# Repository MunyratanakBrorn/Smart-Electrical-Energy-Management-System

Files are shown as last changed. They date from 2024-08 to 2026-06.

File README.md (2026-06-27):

<div align="center">

# ⚡ Smart Electrical Energy Management System
### SEEMS

<p>
  <em>A distributed IoT platform for real-time monitoring, control, and optimization of electrical energy.</em>
</p>

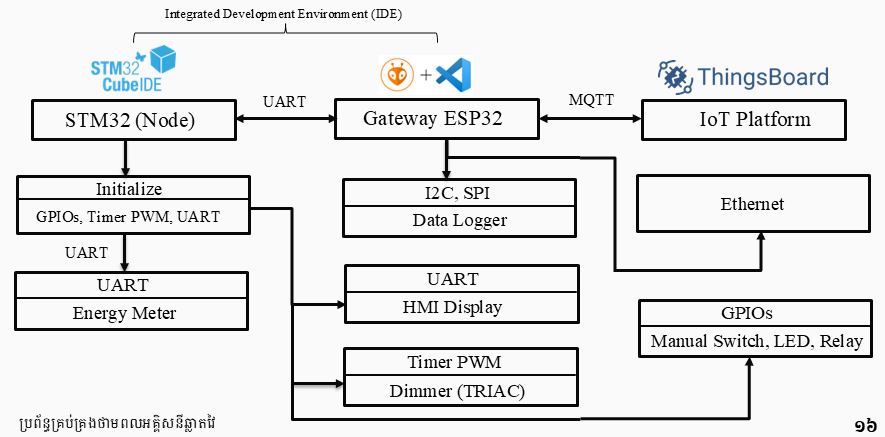
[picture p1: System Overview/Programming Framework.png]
SEEMS System Diagram


<br><br>








</div>

> 💡 **This is a public template.** Use it to bootstrap your own energy-monitoring node — click **"Use this template"** above.

---

## 📌 Table of Contents

- [About the Project](#-about-the-project)
- [Key Features](#-key-features)
- [System Architecture](#-system-architecture)
- [End-to-End Workflow](#-end-to-end-workflow)
- [Project Visuals](#-project-visuals)
- [Tech Stack](#-tech-stack)
- [Hardware Components](#-hardware-components)
- [Communication Protocols](#-communication-protocols)
- [Getting Started](#-getting-started)
- [Repository Structure](#-repository-structure)
- [Authors](#-authors)
- [License](#-license)

---

## 🌐 About the Project

The **Smart Electrical Energy Management System (SEEMS)** is a scalable, IoT-based solution that monitors, controls, and optimizes electrical energy consumption in real time. Built on a **distributed architecture** — STM32 controller nodes paired with an ESP32 gateway and a **ThingsBoard cloud platform** — the system is suitable for **residential, commercial, and industrial** deployments.

Developed as a **Final Year Thesis** for the **Bachelor of Technology in Electronics Engineering** at **Preah Kossomak Polytechnic Institute** (Class of 2024).

---

## ✨ Key Features

| | Feature | Description |
|---|---|---|
| 📊 | **Real-Time Monitoring** | Live voltage, current, power, and energy readings |
| 🎛️ | **Local & Remote Control** | Switch loads via HMI touchscreen or remotely over the cloud |
| ☁️ | **Cloud Dashboard (ThingsBoard)** | Remote telemetry, visualization, and control via MQTT |
| 🔆 | **Dimmer Control (TRIAC)** | Phase-angle dimming for adjustable loads |
| 🧩 | **Distributed & Modular** | Add controller nodes without re-architecting the system |
| 🗄️ | **Onboard Data Logging** | Local logging over I2C/SPI for resilience |
| 🖥️ | **Intuitive HMI** | Touch dashboard built with SquareLine Studio |
| 🔌 | **Reliable Actuation** | Relay-based load switching with safe-state handling |

---

## 🧠 System Architecture

SEEMS follows a **gateway–node** topology. A central **ESP32 gateway** coordinates one or more **STM32F405 controller nodes** for local sensing and actuation, then publishes telemetry to the **ThingsBoard IoT platform** over **MQTT** for remote monitoring and control.

<div align="center">
  <a href="System Overview/Hardware System diagram.jpg" target="_blank">
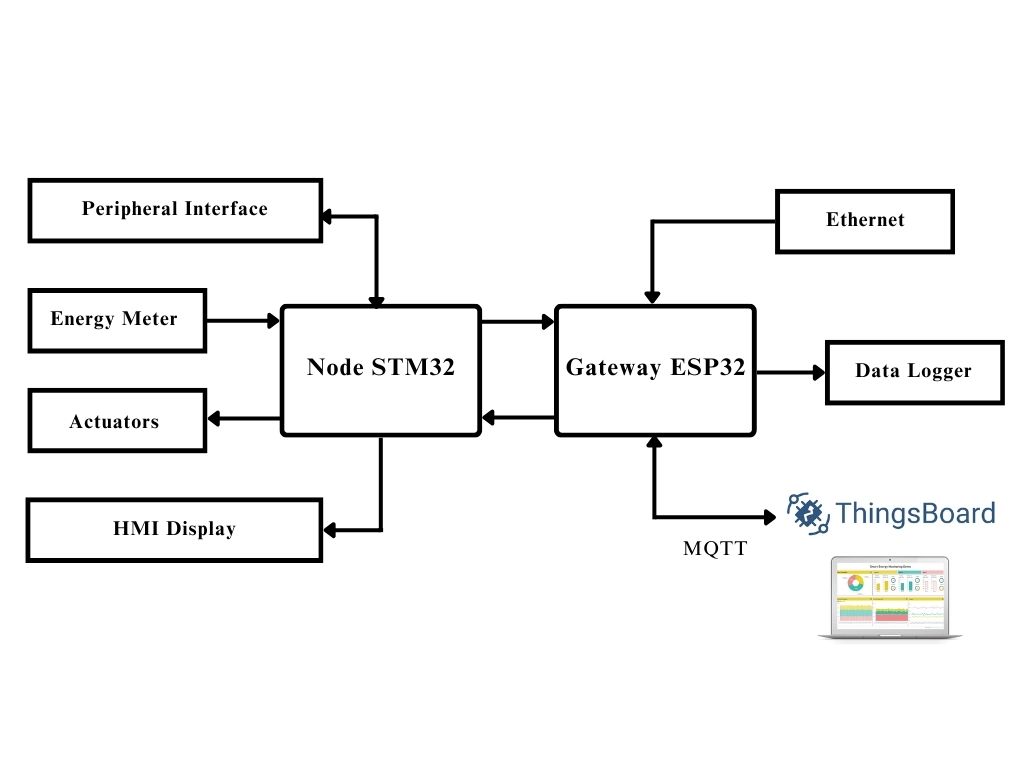
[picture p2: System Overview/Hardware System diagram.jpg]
SEEMS Architecture Diagram
    
  </a>
  <br>
  <em>Click to view full resolution.</em>
</div>

| Layer | Component | Responsibility |
|---|---|---|
| **Edge** | STM32F405 Node | Measure V/I, compute power & energy, drive relays & TRIAC dimmer |
| **Gateway** | ESP32-WROOM-32U | Aggregate data, manage Wi-Fi/Ethernet, publish MQTT to cloud |
| **Cloud** | ThingsBoard | Remote dashboards, telemetry storage, control commands |
| **Interface** | HMI Display | Real-time feedback and local user control |
| **Logging** | Data Logger (I2C/SPI) | Persist measurements locally |

---

## 🔄 End-to-End Workflow

```mermaid
flowchart LR
    A[AC Load] -->|sensing| B[Energy Meter<br/>BL0910]
    B -->|UART| C[STM32F405<br/>Controller Node]
    C -->|power / energy| D[HMI Display]
    C -->|I2C / SPI| H[Data Logger]
    C -->|UART| E[ESP32 Gateway]
    E -->|MQTT over Wi-Fi / Ethernet| F[(ThingsBoard<br/>IoT Platform)]
    F -->|remote command| E
    D -->|local command| C
    E -->|control| C
    C -->|Relay switch| G[Load ON/OFF]
    C -->|Timer PWM| I[TRIAC Dimmer]
```

**Sequence**

1. **Measurement** — The BL0910 IC senses AC voltage and current.
2. **Processing** — The STM32F405 computes power and energy metrics.
3. **Display & Logging** — Results are pushed to the HMI and logged locally via I2C/SPI.
4. **Communication** — Data travels to the ESP32 over UART.
5. **Gateway & Cloud** — The ESP32 publishes telemetry to ThingsBoard via MQTT (over Wi-Fi/Ethernet).
6. **Actuation** — Relays switch loads and the TRIAC dimmer adjusts brightness, based on local or remote input.

---

## 🎬 Live Demo

<div align="center">
  SEEMS animated demo: relay ON/OFF switching and live energy metering
  <br>
  <em>Animated overview — relay <strong>ON/OFF</strong> load switching and live <strong>energy metering</strong> (voltage, current, power, energy).</em>
</div>

> ℹ️ The animation is an inline SVG (`seems-animation.svg`) — it plays automatically on GitHub with no external dependencies.

---

## 🖼️ Project Visuals

<table>
  <tr>
    <th align="center">Main Dashboard</th>
    <th align="center">Real-Time Graph</th>
  </tr>
  <tr>
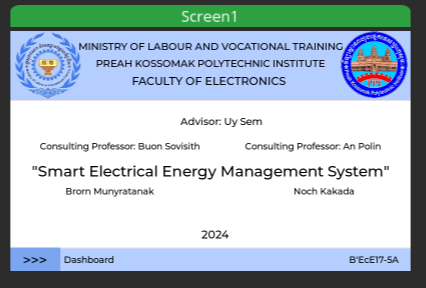
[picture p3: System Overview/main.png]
    <td></td>
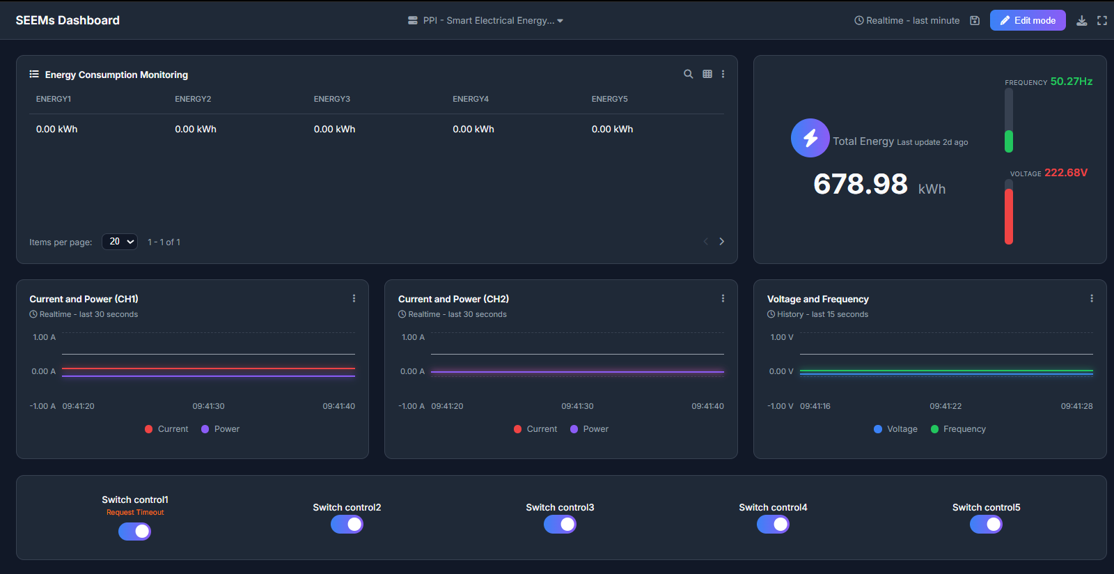
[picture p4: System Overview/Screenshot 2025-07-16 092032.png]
    <td></td>
  </tr>
</table>

---

## 🧰 Tech Stack

**Languages:** C · C++

| Target | Toolchain / Framework |
|---|---|
| ESP32 Gateway | PlatformIO + Arduino Framework |
| STM32 Node | STM32CubeIDE (HAL) |
| HMI | SquareLine Studio |
| Cloud Platform | ThingsBoard (MQTT) |

---

## 🔩 Hardware Components

| Component | Description | Role |
|---|---|---|
| **ESP32-WROOM-32U** | Wi-Fi-enabled MCU | Data aggregation, MQTT cloud gateway |
| **STM32F405RG** | High-performance Cortex-M4 MCU | Sensing, processing, load & dimmer control |
| **BL0910** | Energy metering IC | AC voltage/current sensing |
| **TRIAC Dimmer** | Phase-angle control circuit | Adjustable lighting/load dimming |
| **HMI Display** | SquareLine Studio UI | User interface |
| **12V Songle Relays** | Electromechanical switch | Load on/off control |
| **Data Logger** | I2C/SPI storage | Local measurement logging |

---

## 🔗 Communication Protocols

| Protocol | Link | Purpose |
|---|---|---|
| **UART** | STM32 ↔ ESP32 · STM32 ↔ Energy Meter | Inter-MCU & sensor data exchange |
| **MQTT** | ESP32 ↔ ThingsBoard | Cloud telemetry & remote control |
| **Wi-Fi / Ethernet** | ESP32 ↔ Network | Internet connectivity |
| **I2C / SPI** | STM32 ↔ Data Logger | Local data logging |
| **Timer PWM** | STM32 ↔ TRIAC | Phase-angle dimming control |

---

## 🚀 Getting Started

### Prerequisites

- [STM32CubeIDE](https://www.st.com/en/development-tools/stm32cubeide.html)
- [PlatformIO for VS Code](https://platformio.org/)
- A [ThingsBoard](https://thingsboard.io/) account or self-hosted instance
- Hardware components listed above

### Hardware Setup

1. Assemble components per the schematics in `Hardware/`.
2. Verify connections between the STM32, ESP32, BL0910 sensors, data logger, TRIAC dimmer, and HMI.

### Firmware Upload

| Target | Steps |
|---|---|
| **STM32 Node** | Open `Firmware/STM32_F405_Controller Node/` in STM32CubeIDE → build → flash |
| **ESP32 Gateway** | Open `Firmware/ESP32_Gateway_SEEMs/` in PlatformIO → set Wi-Fi + ThingsBoard MQTT credentials → upload |
| **HMI** | Open `Firmware/HMI Screen display/` in SquareLine Studio → export → load `.tft` via SD card |

### Cloud Setup (ThingsBoard)

1. Create a new **Device** in ThingsBoard and copy its access token.
2. Set the token and broker host in the ESP32 firmware configuration.
3. Import or build a dashboard to visualize incoming telemetry.

### Run

1. Power on all devices.
2. The HMI loads the dashboard.
3. The ESP32 connects to the network and publishes telemetry to ThingsBoard.
4. The system is live for real-time local **and** remote monitoring and control.

---

## 📁 Repository Structure

```
📦 SEEMS
├── 📂 Firmware/
│   ├── 📂 ESP32_Gateway_SEEMs/
│   ├── 📂 STM32_F405_Controller Node/
│   └── 📂 HMI Screen display/
├── 📂 Hardware/
├── 📂 System Overview/
├── 📂 Thesis Report and presentation/
└── 📄 README.md
```

---

## 👥 Authors

| Name | Role |
|---|---|
| **Brorn Munyratanak** | Co-developer |
| **Noch Kakada** | Co-developer |

Final Year Thesis · **Electronics Engineering** · **Preah Kossomak Polytechnic Institute** (Class of 2024)

> Special thanks to our advisors and faculty for their guidance throughout the project.

---

## 📜 License

Licensed under the [MIT License](https://opensource.org/licenses/MIT).

<div align="center">
  <sub>Built with ⚡ for a smarter, more efficient energy future.</sub>
</div>

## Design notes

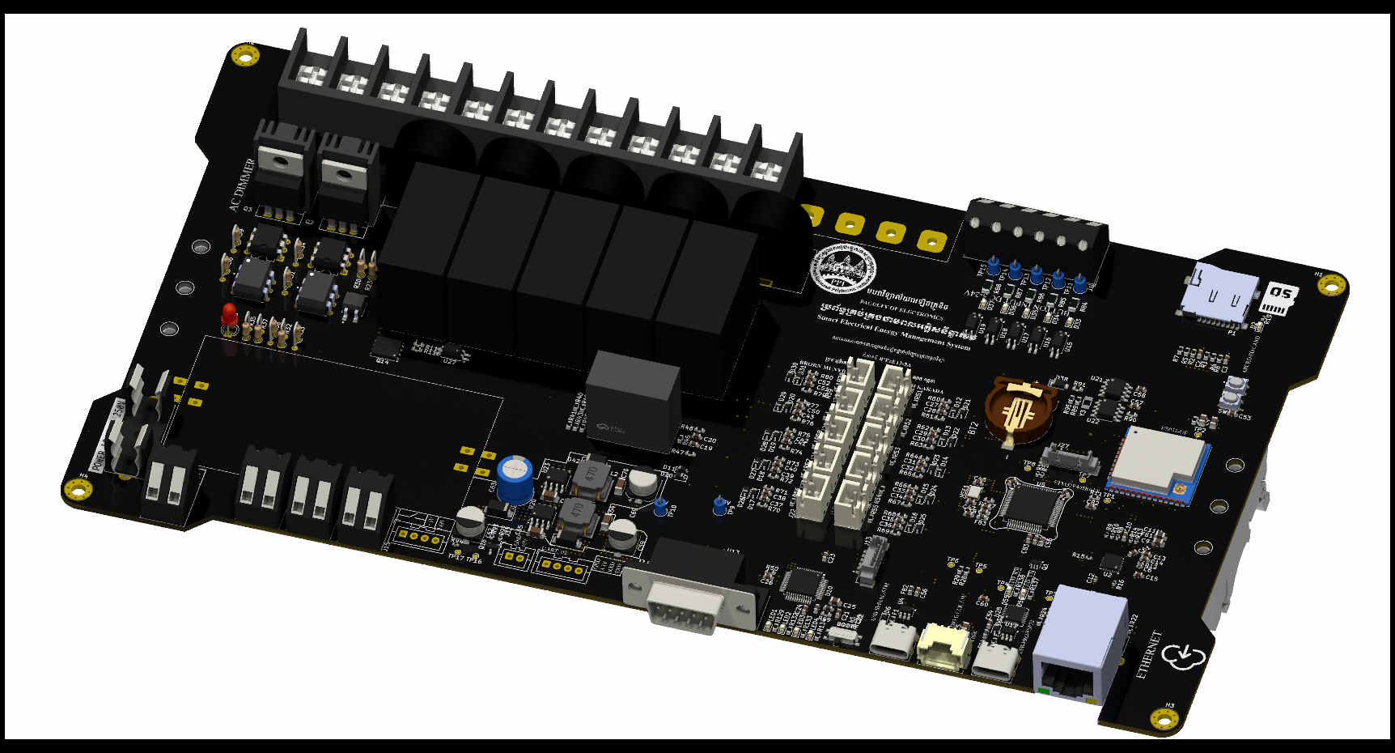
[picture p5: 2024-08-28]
Hardware/SmartEnergyMag_System PCB deisgn/SmartEnergyMag_System2.png

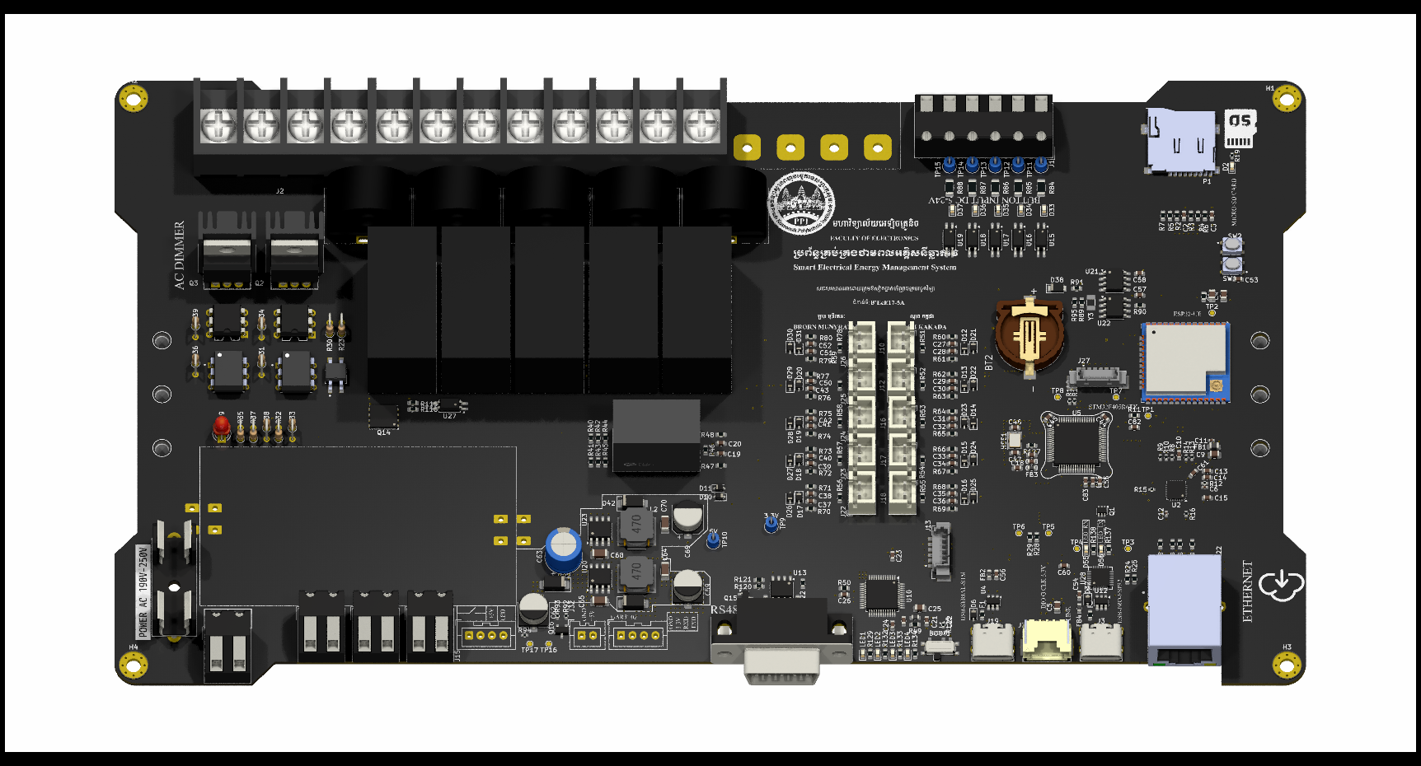
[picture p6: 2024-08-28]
Hardware/SmartEnergyMag_System PCB deisgn/SmartEnergyMag_System3.png

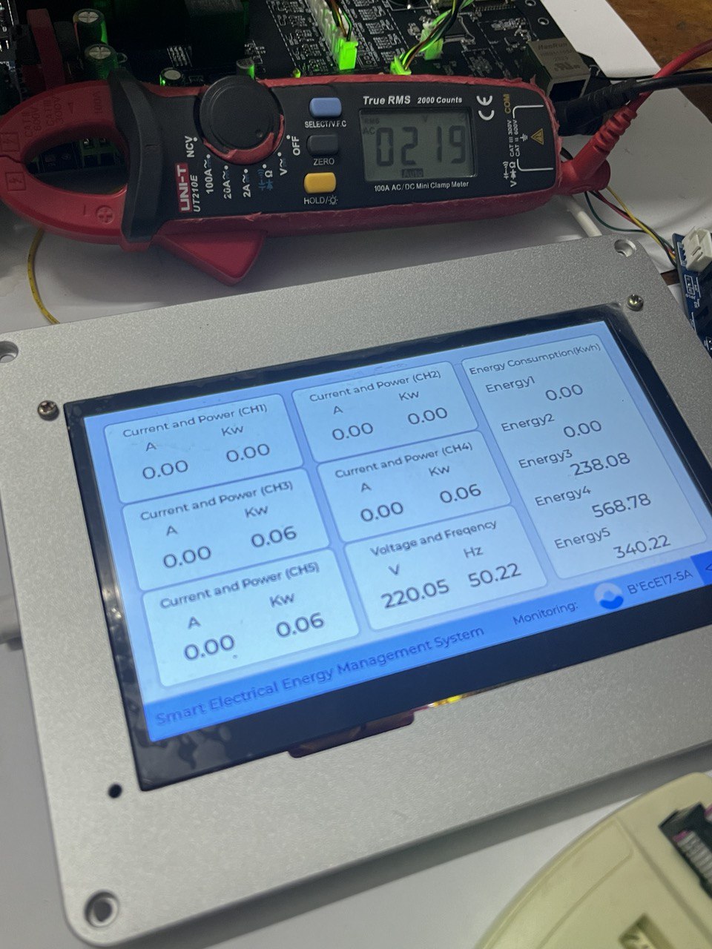
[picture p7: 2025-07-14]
System Overview/dasborad.jpg

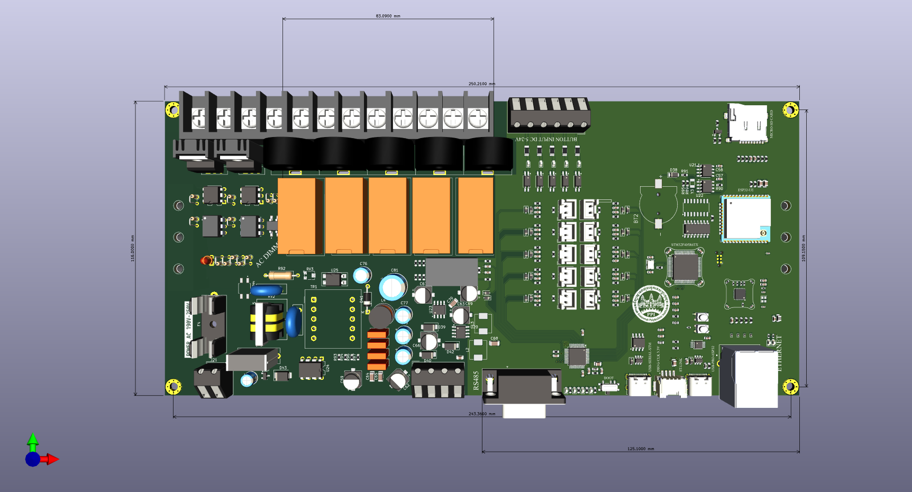
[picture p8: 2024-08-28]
Hardware/SmartEnergyMag_System PCB deisgn/SmartEnergyMag_System1.png

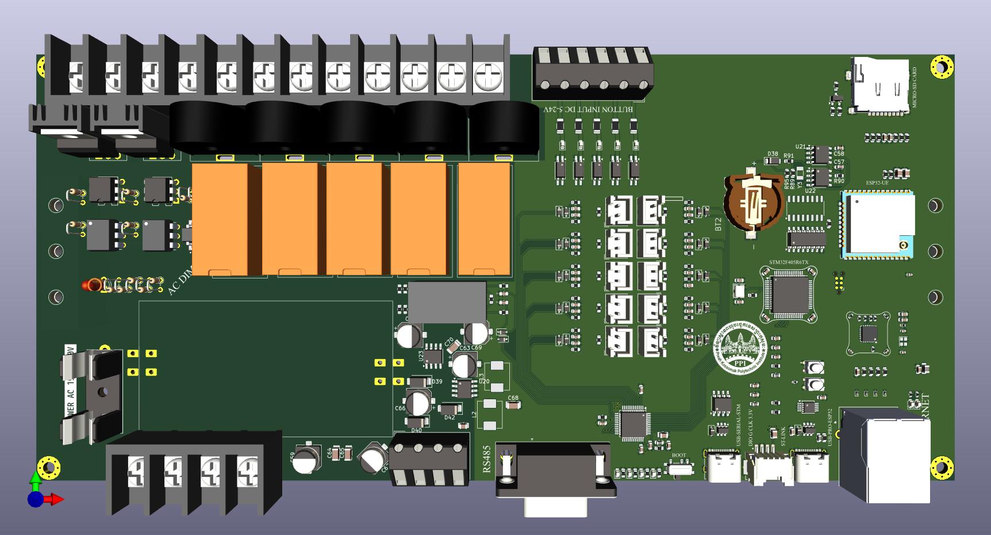
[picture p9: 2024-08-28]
Hardware/SmartEnergyMag_System PCB deisgn/SmartEnergyMag_System.jpg

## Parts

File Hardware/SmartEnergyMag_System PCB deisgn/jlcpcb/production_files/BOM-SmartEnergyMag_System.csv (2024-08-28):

Comment | Designator | Footprint | LCSC
XL1509-3.3 | U20 | SOIC-8_3.9x4.9mm_P1.27mm | C2681226
XL1509-5.0 | U23 | SOIC-8_3.9x4.9mm_P1.27mm | C2902368
510R | R84,R85,R86,R87,R88 | R_1206_3216Metric | C3017298
220uF/16V | C59,C62,C63,C69 | CP_Elec_6.3x4.5 | C59918
C7506797 | J19 | USB_C_Receptacle_G-Switch_GT-USB-7010ASV | C7506797
30R | R59 | R_0603_1608Metric
Conn_01x02_Pin | J26 | JST_XH_B2B-XH-A_1x02_P2.50mm_Vertical
10K | R3 | R_0603_1608Metric
100n | C60 | C_0603_1608Metric
330 | R133 | R_0603_1608Metric
Relay_SPST-NO | K1 | K88A
MOC3021M | U7 | DIP-6_W7.62mm
LED | D36 | LED_0603_1608Metric
Conn_01x02_Pin | J22 | JST_XH_B2B-XH-A_1x02_P2.50mm_Vertical
1N4148WS | D17 | D_SOD-323
49.9R | R20 | R_0603_1608Metric
1K | R31 | R_Axial_DIN0204_L3.6mm_D1.6mm_P2.54mm_Vertical
30R | R53 | R_0603_1608Metric
33nF | C26 | C_0603_1608Metric
Relay_SPST-NO | K5 | K88A
0R | R15 | R_0402_1005Metric
30R | R52 | R_0603_1608Metric
30R | R78 | R_0603_1608Metric
1N4148WS | D11 | D_SOD-323
33nF | C32 | C_0603_1608Metric
510R | R69 | R_0603_1608Metric
47K | R23 | R_Axial_DIN0204_L3.6mm_D1.6mm_P2.54mm_Vertical
CH330N | U6 | SOIC-8_3.9x4.9mm_P1.27mm
100n | C54 | C_0603_1608Metric
510R | R63 | R_0603_1608Metric
330 | R33 | R_Axial_DIN0204_L3.6mm_D1.6mm_P2.54mm_Vertical
2K | R50 | R_0603_1608Metric
0.1A | F3 | Fuse_1206_3216Metric
10K | R8 | R_0402_1005Metric
10uF/10V | C25 | C_0805_2012Metric
30R | R55 | R_0603_1608Metric
Conn_01x02_Pin | J25 | JST_XH_B2B-XH-A_1x02_P2.50mm_Vertical
330 | R132 | R_0603_1608Metric
30R | R58 | R_0603_1608Metric
33nF | C36 | C_0603_1608Metric
D_Schottky | D32 | D_SOD-323
33nF | C34 | C_0603_1608Metric
510R | R61 | R_0603_1608Metric
5.1K | R81 | R_0603_1608Metric
30R | R56 | R_0603_1608Metric
MountingHole_Pad | H2 | MountingHole_3.2mm_M3_Pad_Via
Conn_01x02_Pin | J18 | JST_XH_B2B-XH-A_1x02_P2.50mm_Vertical
0R | R22 | R_0603_1608Metric
510R | R79 | R_0603_1608Metric
5.1K | R26 | R_0603_1608Metric
49.9R | R21 | R_0603_1608Metric
510R | R67 | R_0603_1608Metric
1N4148WS | D18 | D_SOD-323
LED | D9 | LED_D3.0mm
Conn_01x02_Pin | J9 | ZHT103
33nF | C50 | C_0603_1608Metric
12.1K | R16 | R_0402_1005Metric
1N4148WS | D21 | D_SOD-323
510R | R64 | R_0603_1608Metric
1K | R24 | R_0603_1608Metric
510R | R62 | R_0603_1608Metric
510R | R76 | R_0603_1608Metric
510R | R73 | R_0603_1608Metric
MAX485E | U13 | SOIC-8_3.9x4.9mm_P1.27mm
10K | R10 | R_0402_1005Metric
C3015389 | U19 | SOP-4_4.4x2.6mm_P1.27mm
510R | R60 | R_0603_1608Metric
1K | R35 | R_Axial_DIN0204_L3.6mm_D1.6mm_P2.54mm_Vertical
1N4148WS | D13 | D_SOD-323
2.2uF | C1 | C_0805_2012Metric
DIN_Rail_Adapter | DRA1 | DINRailAdapter_3xM3_PhoenixContact_1201578
220K | R19 | R_0603_1608Metric
Conn_01x02_Pin | J17 | JST_XH_B2B-XH-A_1x02_P2.50mm_Vertical
Conn_01x02_Pin | J24 | JST_XH_B2B-XH-A_1x02_P2.50mm_Vertical
R | LED2 | LED_0603_1608Metric
100n | C53 | C_0603_1608Metric
220R | R46 | R_0603_1608Metric
100nF | C11 | C_0402_1005Metric
33nF | C28 | C_0603_1608Metric
C221895 | SW2 | SW_PTS810_SJM_250_SMTR_LFS
Conn_01x02_Pin | J16 | JST_XH_B2B-XH-A_1x02_P2.50mm_Vertical
100nF | C2 | C_0603_1608Metric
USB_C_Receptacle_USB2.0_16P | J3 | USB_C_Receptacle_G-Switch_GT-USB-7010ASV
MCT2E | U8 | DIP762W50P254L742H480Q6
Heatsink_Pad | HS2 | HSINK_SK_95_25_STS_TO_220
MOC3021M | U9 | DIP-6_W7.62mm
33nF | C33 | C_0603_1608Metric
C328062 | U1 | ESP32-WROOM-32U
ESD9B3.3ST5G | D1 | D_SOD-923
22K | R43 | R_0603_1608Metric
1N4148WS | D14 | D_SOD-323
100n | C61 | C_0603_1608Metric
Screw_Terminal_01x04 | J2 | DBT50G-9.5-4P
100 | R134 | R_0603_1608Metric
5.1K | R27 | R_0603_1608Metric
33nF | C29 | C_0603_1608Metric
FB_Small | FB2 | L_0603_1608Metric
22R | R6 | R_0603_1608Metric
22K | R45 | R_0603_1608Metric
33nF | C39 | C_0603_1608Metric
510R | R70 | R_0603_1608Metric
C3015389 | U18 | SOP-4_4.4x2.6mm_P1.27mm
5.1K | R82 | R_0603_1608Metric
NC | C6 | C_0402_1005Metric
MountingHole_Pad | H4 | MountingHole_3.2mm_M3_Pad_Via
LED | D35 | LED_0603_1608Metric
C62892 | Q1 | SOT-363_SC-70-6
BL0910 | U10 | LQFP-48_7x7mm_P0.5mm
100nF | C10 | C_0603_1608Metric
1N4148WS | D29 | D_SOD-323
Conn_01x02_Pin | J14 | JST_XA_B02B-XASK-1_1x02_P2.50mm_Vertical
Screw_Terminal_01x02 | J21 | Altech_AK300_1x02_P5.00mm_45-Degree
1N4148WS | D26 | D_SOD-323
33nF | C20 | C_0603_1608Metric
30R | R54 | R_0603_1608Metric
Screw_Terminal_01x04 | J11 | DBT50G-9.5-4P
33nF | C40 | C_0603_1608Metric
BT136-600 | Q2 | TO-220-3_Vertical
510R | R47 | R_0603_1608Metric
100n | C44 | C_0603_1608Metric
1uF | C14 | C_0603_1608Metric
Ferrite_Bead_Small | FB3 | L_0603_1608Metric
HR911105A | J4 | HANRUN_HR911105A
Screw_Terminal_01x06 | J1 | Altech_AK300_1x06_P5.00mm_45-Degree
MCT2E | U3 | DIP762W50P254L742H480Q6
510R | R80 | R_0603_1608Metric
0533980671 | J13 | MOLEX_0533980671
100n | C16 | C_0603_1608Metric
1N4148WS | D19 | D_SOD-323
C221895 | SW1 | SW_PTS810_SJM_250_SMTR_LFS
MountingHole_Pad | H1 | MountingHole_3.2mm_M3_Pad_Via
Conn_01x02_Pin | J23 | JST_XH_B2B-XH-A_1x02_P2.50mm_Vertical
1N4148WS | D20 | D_SOD-323
510R | R75 | R_0603_1608Metric
1N4148WS | D23 | D_SOD-323
Conn_01x02_Pin | J10 | JST_XH_B2B-XH-A_1x02_P2.50mm_Vertical
30R | R57 | R_0603_1608Metric
USBLC6 | U4 | SOT-23-6
Conn_01x02_Pin | J12 | JST_XH_B2B-XH-A_1x02_P2.50mm_Vertical
C139168 | FB1 | L_0805_2012Metric
1N4148WS | D12 | D_SOD-323
1K | R36 | R_Axial_DIN0204_L3.6mm_D1.6mm_P2.54mm_Vertical
HPT225A-G | T1 | HPT225A-G
49.9R | R17 | R_0603_1608Metric
DIN_Rail_Adapter | DRA2 | DINRailAdapter_3xM3_PhoenixContact_1201578
33nF | C43 | C_0603_1608Metric
10K | R2 | R_0603_1608Metric
1N4148WS | D28 | D_SOD-323
1K | R25 | R_0603_1608Metric
22uF | C9 | C_0805_2012Metric
33nF | C23 | C_0603_1608Metric
620 | R127 | R_0603_1608Metric
33nF | C52 | C_0603_1608Metric
C7529389 | P1 | SUNTECH_ST-TF-003A
4.7K | R11 | R_0603_1608Metric
10K | R13 | R_0402_1005Metric
510R | R66 | R_0603_1608Metric
Screw_Terminal_01x04 | J5 | DBT50G-9.5-4P
Relay_SPST-NO | K2 | K88A
LED | D37 | LED_0603_1608Metric
1N4148WS | D15 | D_SOD-323
33nF | C41 | C_0603_1608Metric
Conn_01x04_Pin | J20 | JST_XA_B04B-XASK-1_1x04_P2.50mm_Vertical
ESD9B3.3ST5G | D4 | D_SOD-923
SW_DPDT_x2 | BOOT1 | SW_SPDT_PCM12
MBS6 | D8 | DIOB_MBS6
100K | R1 | R_0603_1608Metric
100nF | C22 | C_0603_1608Metric
C15742 | U5 | LQFP-64_10x10mm_P0.5mm
22R | R4 | R_0603_1608Metric
LED | D34 | LED_0603_1608Metric
Relay_SPST-NO | K3 | K88A
Conn_01x02_Pin | J8 | ZHT103
510R | R74 | R_0603_1608Metric
Y | LED3 | LED_0603_1608Metric
R | LED1 | LED_0603_1608Metric
22uF | C5 | C_0805_2012Metric
Fuse | F2 | Fuseholder_Cylinder-5x20mm_Schurter_0031_8201_Horizontal_Open
22uF | C4 | C_0805_2012Metric
330 | R34 | R_Axial_DIN0204_L3.6mm_D1.6mm_P2.54mm_Vertical
100n | C55 | C_0603_1608Metric
D_Schottky | D6 | D_SOD-323
33nF | C24 | C_0603_1608Metric
ESD9B3.3ST5G | D3 | D_SOD-923
33nF | C30 | C_0603_1608Metric
510R | R72 | R_0603_1608Metric
1N4148WS | D27 | D_SOD-323
ESD9B3.3ST5G | D5 | D_SOD-923
470pF | C13 | C_0603_1608Metric
33nF | C37 | C_0603_1608Metric
510R | R68 | R_0603_1608Metric
10K | R37 | R_Axial_DIN0204_L3.6mm_D1.6mm_P2.54mm_Vertical
22R | R7 | R_0603_1608Metric
30pF | C15 | C_0603_1608Metric
DE9_Plug_MountingHoles | J7 | DSUB-9_Male_Horizontal_P2.77x2.84mm_EdgePinOffset4.94mm_Housed_MountingHolesOffset7.48mm
10p | C46 | C_0603_1608Metric
LED | D2 | LED_0603_1608Metric
1N4148WS | D25 | D_SOD-323
10K | R9 | R_0402_1005Metric
22K | R42 | R_0603_1608Metric
220R | R49 | R_0603_1608Metric
100n | C49 | C_0603_1608Metric
8MHz | HSE1 | Crystal_SMD_Abracon_ABM8G-4Pin_3.2x2.5mm
10p | C47 | C_0603_1608Metric
510R | R71 | R_0603_1608Metric
100n | C56 | C_0603_1608Metric
22K | R41 | R_0603_1608Metric
1N4148WS | D10 | D_SOD-323
22K | R44 | R_0603_1608Metric
30R | R51 | R_0603_1608Metric
1N4148WS | D16 | D_SOD-323
FB_Small | FB4 | L_0603_1608Metric
BT136-600 | Q3 | TO-220-3_Vertical
330 | R39 | R_Axial_DIN0204_L3.6mm_D1.6mm_P2.54mm_Vertical
33nF | C35 | C_0603_1608Metric
LAN8720A | U2 | VQFN-24-1EP_4x4mm_P0.5mm_EP2.5x2.5mm_ThermalVias
Heatsink_Pad | HS1 | HSINK_SK_95_25_STS_TO_220
10K | R125 | R_0402_1005Metric
1uF | C12 | C_0402_1005Metric
33nF | C38 | C_0603_1608Metric
100n | C17 | C_0603_1608Metric
0R | R12 | R_0402_1005Metric
33nF | C42 | C_0603_1608Metric
1N4148WS | D30 | D_SOD-323
LED | D33 | LED_0603_1608Metric
B | LED4 | LED_0603_1608Metric
510R | R77 | R_0603_1608Metric
100n | C45 | C_0603_1608Metric
22K | R40 | R_0603_1608Metric
33nF | C51 | C_0603_1608Metric
C3015389 | U16 | SOP-4_4.4x2.6mm_P1.27mm
1N4148WS | D31 | D_SOD-323
Relay_SPST-NO | K4 | K88A
330 | R38 | R_Axial_DIN0204_L3.6mm_D1.6mm_P2.54mm_Vertical
49.9R | R18 | R_0603_1608Metric
33nF | C31 | C_0603_1608Metric
1uF | C3 | C_0603_1608Metric
33nF | C27 | C_0603_1608Metric
C3015389 | U15 | SOP-4_4.4x2.6mm_P1.27mm
22R | R29 | R_0603_1608Metric
1N4148WS | D24 | D_SOD-323
L | L1 | L_0603_1608Metric
22R | R5 | R_0603_1608Metric
22R | R28 | R_0603_1608Metric
330 | R129 | R_0603_1608Metric
510R | R65 | R_0603_1608Metric
10K | R32 | R_Axial_DIN0204_L3.6mm_D1.6mm_P2.54mm_Vertical
47K | R30 | R_Axial_DIN0204_L3.6mm_D1.6mm_P2.54mm_Vertical
100n | C18 | C_0603_1608Metric
C3015389 | U17 | SOP-4_4.4x2.6mm_P1.27mm
Screw_Terminal_01x04 | J6 | DBT50G-9.5-4P
1u | C48 | C_0603_1608Metric
100nF | C21 | C_0603_1608Metric
USBLC6 | U12 | SOT-23-6
10K | R14 | R_0402_1005Metric
510R | R48 | R_0603_1608Metric
MountingHole_Pad | H3 | MountingHole_3.2mm_M3_Pad_Via
33nF | C19 | C_0603_1608Metric
1N4148WS | D22 | D_SOD-323
TestPoint_Probe | TP6 | TestPoint_Pad_D1.0mm
TestPoint_Probe | TP1 | TestPoint_Pad_D1.0mm
100nF | C57 | C_0603_1608Metric
100K | R89 | R_0603_1608Metric
C | C65 | C_1206_3216Metric
20K | R120 | R_0603_1608Metric
D | D38 | D_SMF
32768Hz | Y3 | Crystal_SMD_3215-2Pin_3.2x1.5mm
0533980671 | J27 | MOLEX_0533980671
CP2102N | U28 | QFN-28-1EP_5x5mm_P0.5mm_EP3.1x3.1mm_ThermalVias
100K | R119 | R_0603_1608Metric
100R | R91 | R_0603_1608Metric
SS34 | D40 | D_SMA
5.1K | R137 | R_0603_1608Metric
10K | R121 | R_0603_1608Metric
C | C64 | C_1206_3216Metric
AT24CS32-SSHM | U21 | SOIC-8_3.9x4.9mm_P1.27mm
10K | R139 | R_0402_1005Metric
C | C70 | C_1206_3216Metric
4.7K | R123 | R_0603_1608Metric
100nF | C58 | C_0603_1608Metric
SS34 | D39 | D_SMA
C | C71 | C_1210_3225Metric
LED_RX | D55 | LED_0603_1608Metric
SS34 | D42 | D_SMA
LED_TX | D56 | LED_0603_1608Metric
C9868 | U22 | SOIC-8_3.9x4.9mm_P1.27mm
Conn_01x02_Pin | J30 | ZHT103
SM04B-ZESS-TB_LF__SN_ | J28 | JST_SM04B-ZESS-TB_LF__SN_
TestPoint_Probe | TP7 | TestPoint_Pad_D1.0mm
TestPoint_Probe | TP8 | TestPoint_Pad_D1.0mm
10K | R90 | R_0603_1608Metric
BSC026N08NS5 | Q14 | TDSON-8-1
4.7K | R124 | R_0603_1608Metric
TestPoint_Probe | TP4 | TestPoint_Pad_D1.0mm
4.7K | R118 | R_0603_1608Metric
C | C68 | C_1206_3216Metric
10K | R122 | R_0603_1608Metric
TestPoint_Probe | TP5 | TestPoint_Pad_D1.0mm
10K | R140 | R_0402_1005Metric
TestPoint_Probe | TP2 | TestPoint_Pad_D1.0mm
C3224219 | L2 | L_Bourns_SRN8040TA
100R | R95 | R_0603_1608Metric
TestPoint_Probe | TP3 | TestPoint_Pad_D1.0mm
10p | C83 | C_0603_1608Metric
Conn_01x02_Pin | J29 | ZHT103
Conn_01x02_Pin | J31 | ZHT103
C3015389 | U27 | SOP-4_4.4x2.6mm_P1.27mm
BC501SM | BT2 | BAT_BC501SM
10p | C82 | C_0603_1608Metric
5.1K | R138 | R_0603_1608Metric
100K | R103 | R_0603_1608Metric
100K | R113 | R_0603_1608Metric
4.7K | R98 | R_0603_1608Metric
100K | R99 | R_0603_1608Metric
SN74LVC1G14DBV | U29 | SOT-23-5
Q_NPN_BEC | Q12 | SOT-23
D | D53 | D_SMF
Q_NPN_BEC | Q10 | SOT-23
SN74LVC1G14DBV | U31 | SOT-23-5
100K | R105 | R_0603_1608Metric
D | D49 | D_SMF
4.7K | R106 | R_0603_1608Metric
Q_NPN_BEC | Q11 | SOT-23
SN74LVC1G14DBV | U32 | SOT-23-5
Q_NPN_BEC | Q9 | SOT-23
D | D45 | D_SMF
4.7K | R116 | R_0603_1608Metric
4.7K | R100 | R_0603_1608Metric
Q_NPN_BEC | Q8 | SOT-23
4.7K | R104 | R_0603_1608Metric
D | D48 | D_SMF
4.7K | R112 | R_0603_1608Metric
4.7K | R114 | R_0603_1608Metric
100K | R115 | R_0603_1608Metric
Q_NPN_BEC | Q4 | SOT-23
Q_NPN_BEC | Q6 | SOT-23
SN74LVC1G14DBV | U33 | SOT-23-5
4.7K | R108 | R_0603_1608Metric
100K | R107 | R_0603_1608Metric
D | D47 | D_SMF
Q_NPN_BEC | Q5 | SOT-23
SN74LVC1G14DBV | U30 | SOT-23-5
D | D52 | D_SMF
D | D50 | D_SMF
100K | R109 | R_0603_1608Metric
100K | R111 | R_0603_1608Metric
Q_NPN_BEC | Q13 | SOT-23
100K | R101 | R_0603_1608Metric
D | D54 | D_SMF
100K | R117 | R_0603_1608Metric
D | D51 | D_SMF
4.7K | R102 | R_0603_1608Metric
D | D46 | D_SMF
Q_NPN_BEC | Q7 | SOT-23
4.7K | R110 | R_0603_1608Metric
Screw_Terminal_01x02 | J33 | Altech_AK300_1x02_P5.00mm_45-Degree
TestPoint | TP17 | TestPoint_Pad_D1.0mm
HLK-12M05A | PS1 | AC-DC
C5199900 | TP14 | TestPoint_Loop_D1.80mm_Drill1.0mm_Beaded
TestPoint_Probe | TP9 | TestPoint_Loop_D1.80mm_Drill1.0mm_Beaded
C5199900 | TP12 | TestPoint_Loop_D1.80mm_Drill1.0mm_Beaded
0.1A | F1 | Fuse_1206_3216Metric
TestPoint | TP16 | TestPoint_Pad_D1.0mm
C5199900 | TP15 | TestPoint_Loop_D1.80mm_Drill1.0mm_Beaded
Screw_Terminal_01x02 | J35 | Altech_AK300_1x02_P5.00mm_45-Degree
C5199900 | TP13 | TestPoint_Loop_D1.80mm_Drill1.0mm_Beaded
Screw_Terminal_01x02 | J34 | Altech_AK300_1x02_P5.00mm_45-Degree
C5199900 | TP11 | TestPoint_Loop_D1.80mm_Drill1.0mm_Beaded
TestPoint_Probe | TP10 | TestPoint_Loop_D1.80mm_Drill1.0mm_Beaded
1K | R92 | R_0402_1005Metric
C5199900 | TP19 | TestPoint_Loop_D1.80mm_Drill1.0mm_Beaded
1K | R94 | R_0402_1005Metric
10R | R128 | R_0603_1608Metric
C3224219 | L4 | L_Bourns_SRN8040TA
0R | R131 | R_0603_1608Metric
Conn_01x04_Pin | J15 | JST_XA_B04B-XASK-1_1x04_P2.50mm_Vertical
Q_PNP_BEC | Q17 | SOT-23
LED | D7 | LED_0603_1608Metric
100nF | C7 | C_0603_1608Metric
C5199900 | TP18 | TestPoint_Loop_D1.80mm_Drill1.0mm_Beaded
DNP | R126 | R_0603_1608Metric
100R | R96 | R_0603_1608Metric
10R | R130 | R_0603_1608Metric
220K | R97 | R_0603_1608Metric
Conn_01x02_Pin | J36 | JST_XA_B02B-XASK-1_1x02_P2.50mm_Vertical
1K | R93 | R_0402_1005Metric
Q_NPN_BEC | Q16 | SOT-23
AP130-33Y | U11 | SOT-89-3
Conn_01x02_Pin | J32 | JST_XA_B02B-XASK-1_1x02_P2.50mm_Vertical
0R | R83 | R_1206_3216Metric
SZNUP2105L | D41 | SOT-23

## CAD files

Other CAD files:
Hardware/SmartEnergyMag_System PCB deisgn/SmartEnergyMag_System v1.f3d

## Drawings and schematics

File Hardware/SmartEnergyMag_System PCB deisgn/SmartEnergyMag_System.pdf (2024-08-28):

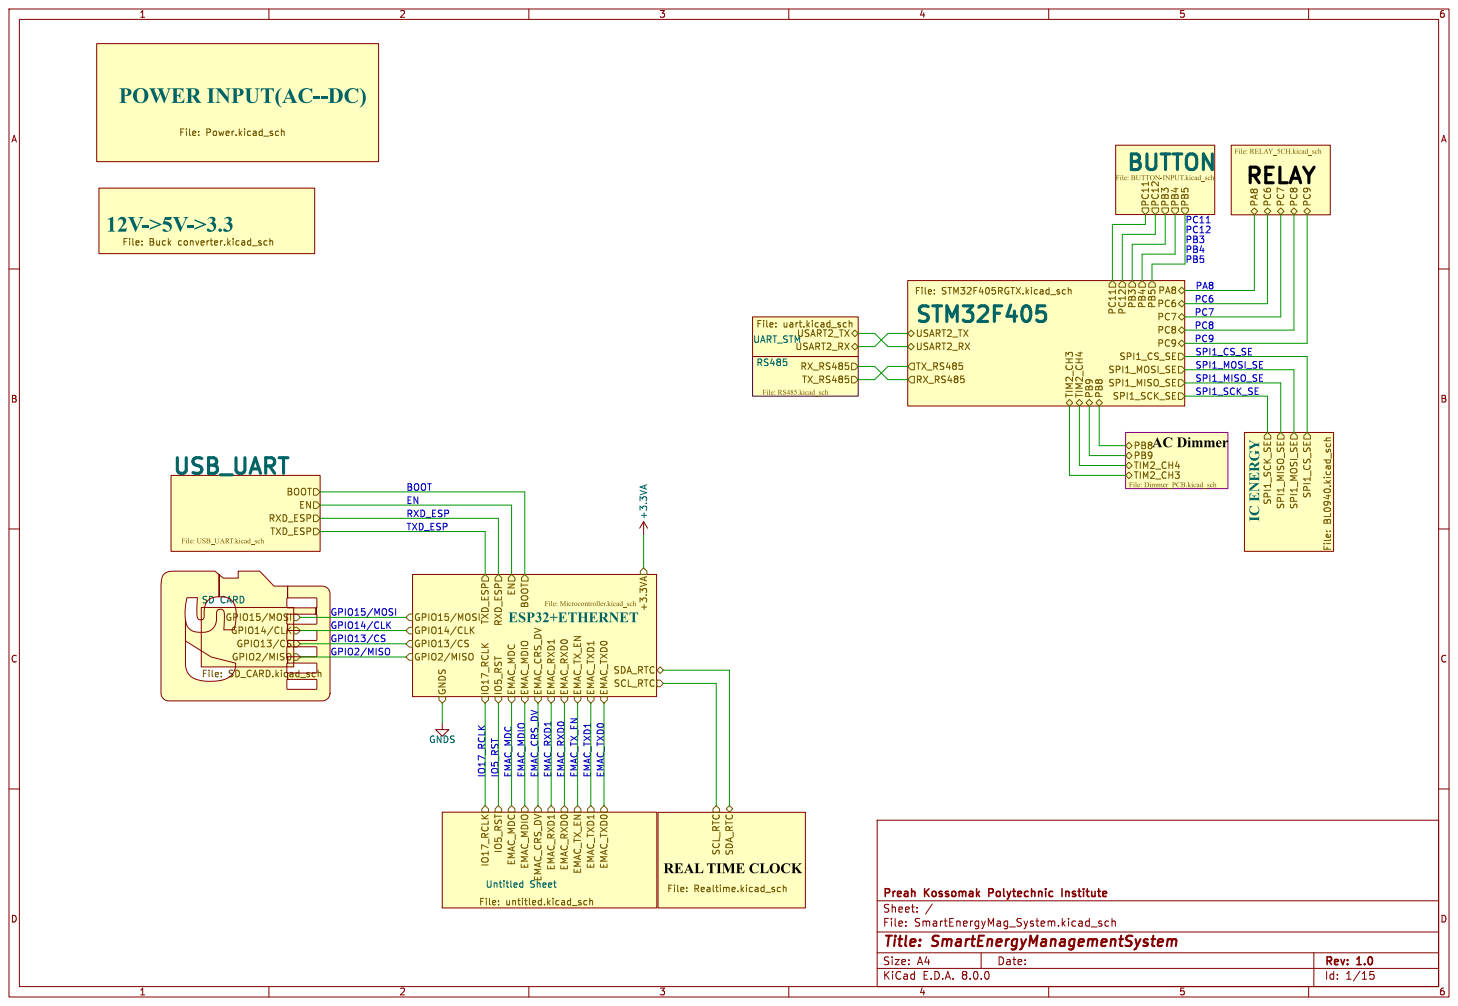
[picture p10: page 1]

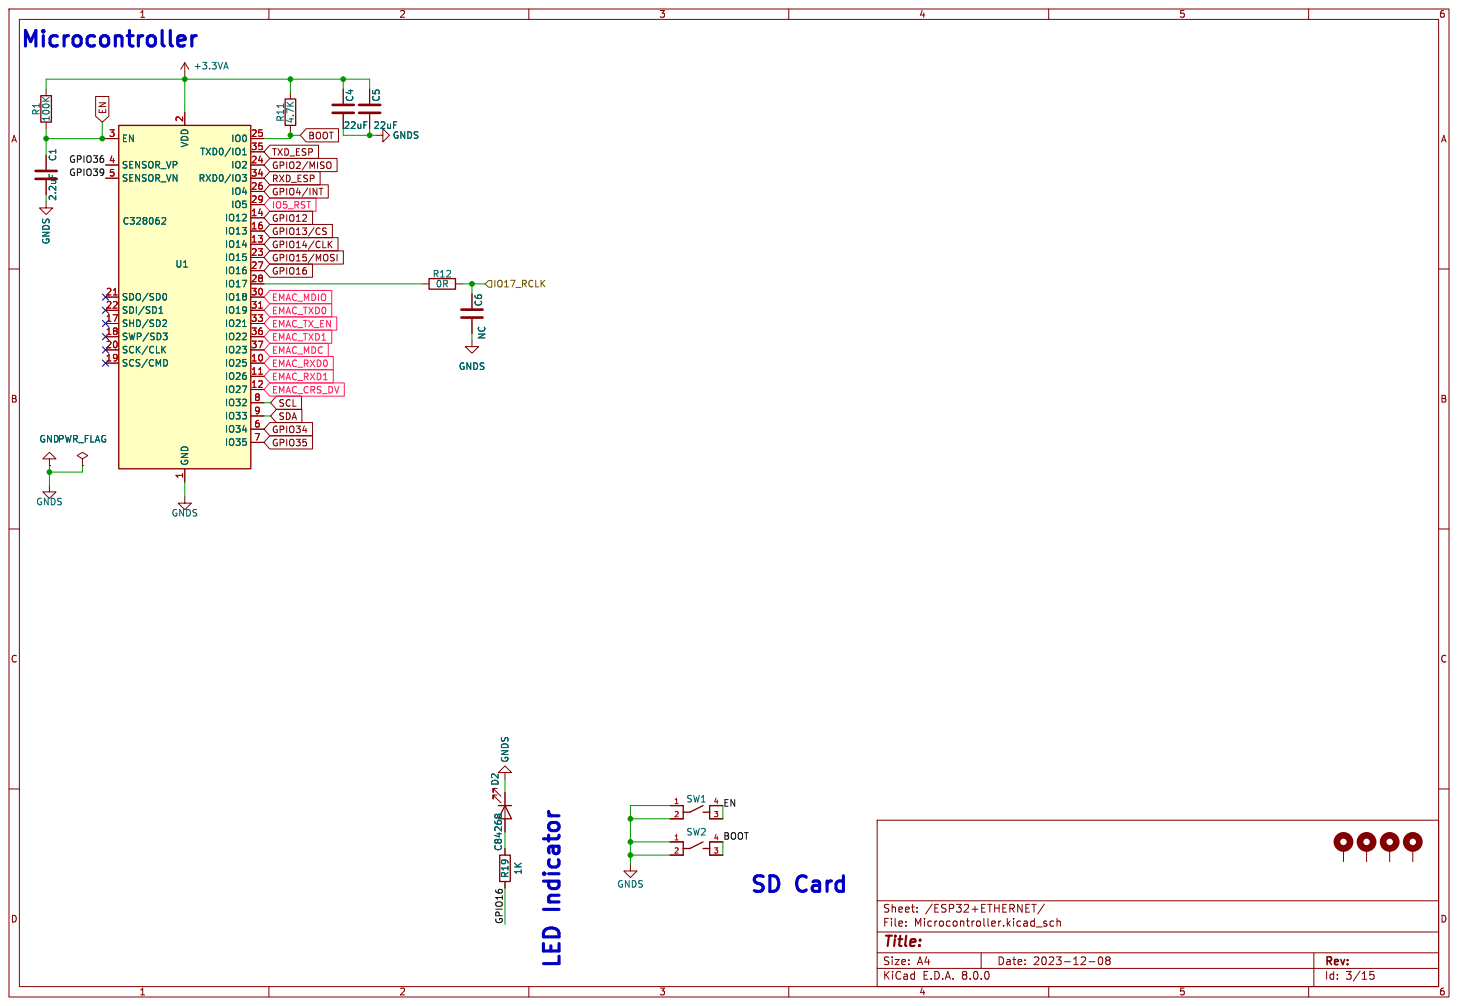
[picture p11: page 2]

Id: 3/15 Title: File: Microcontroller.kicad_sch Sheet: /ESP32+ETHERNET/ GNDS GNDS

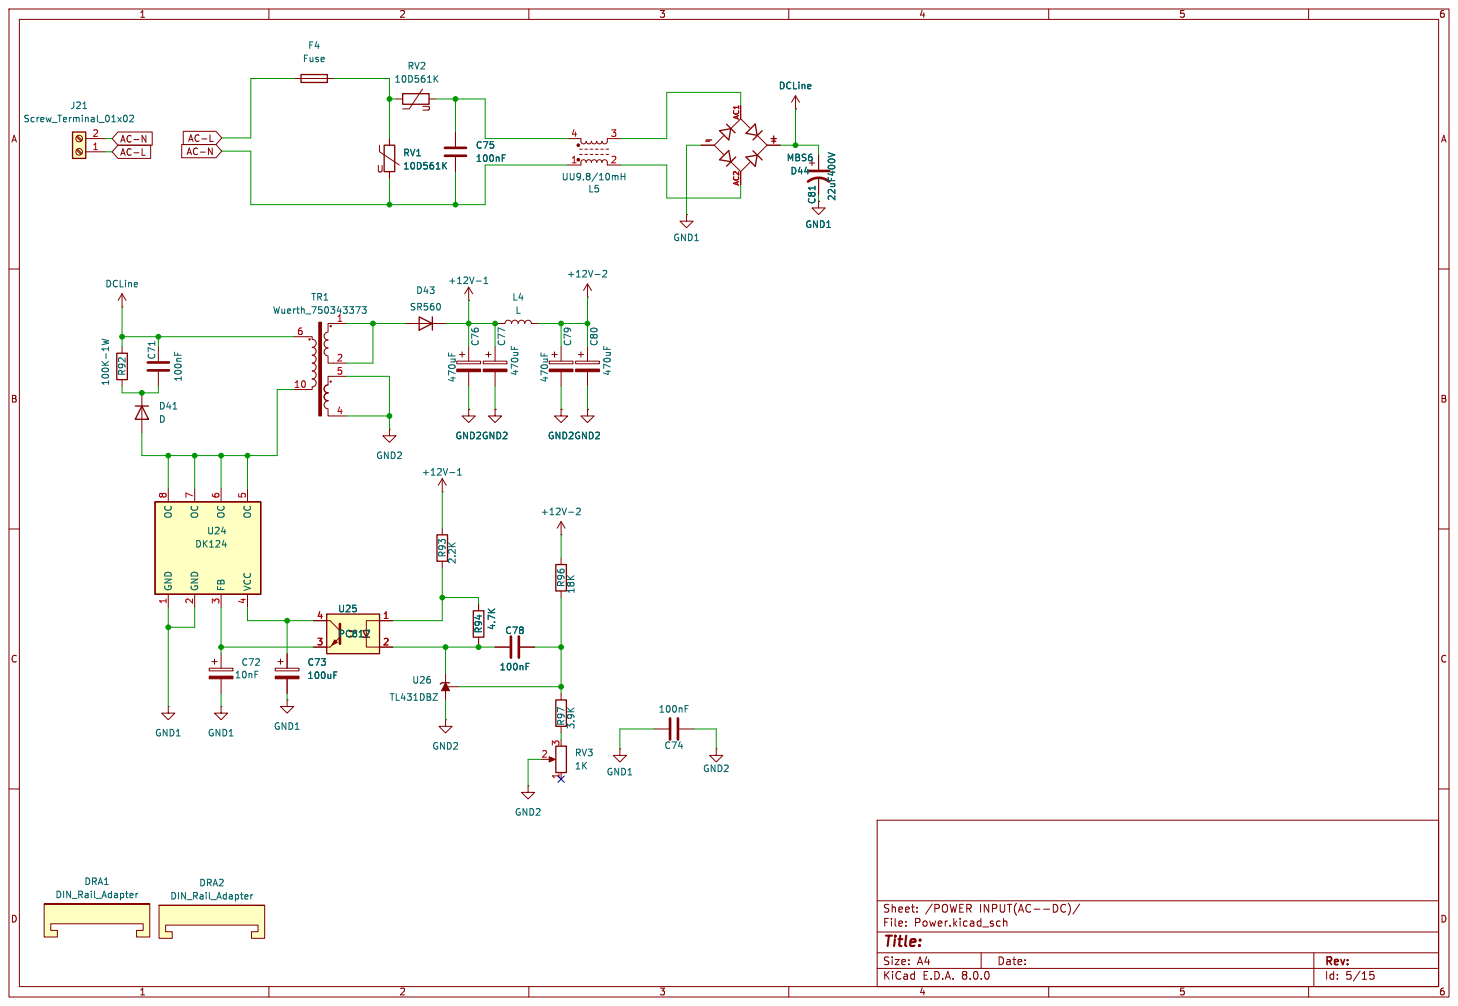
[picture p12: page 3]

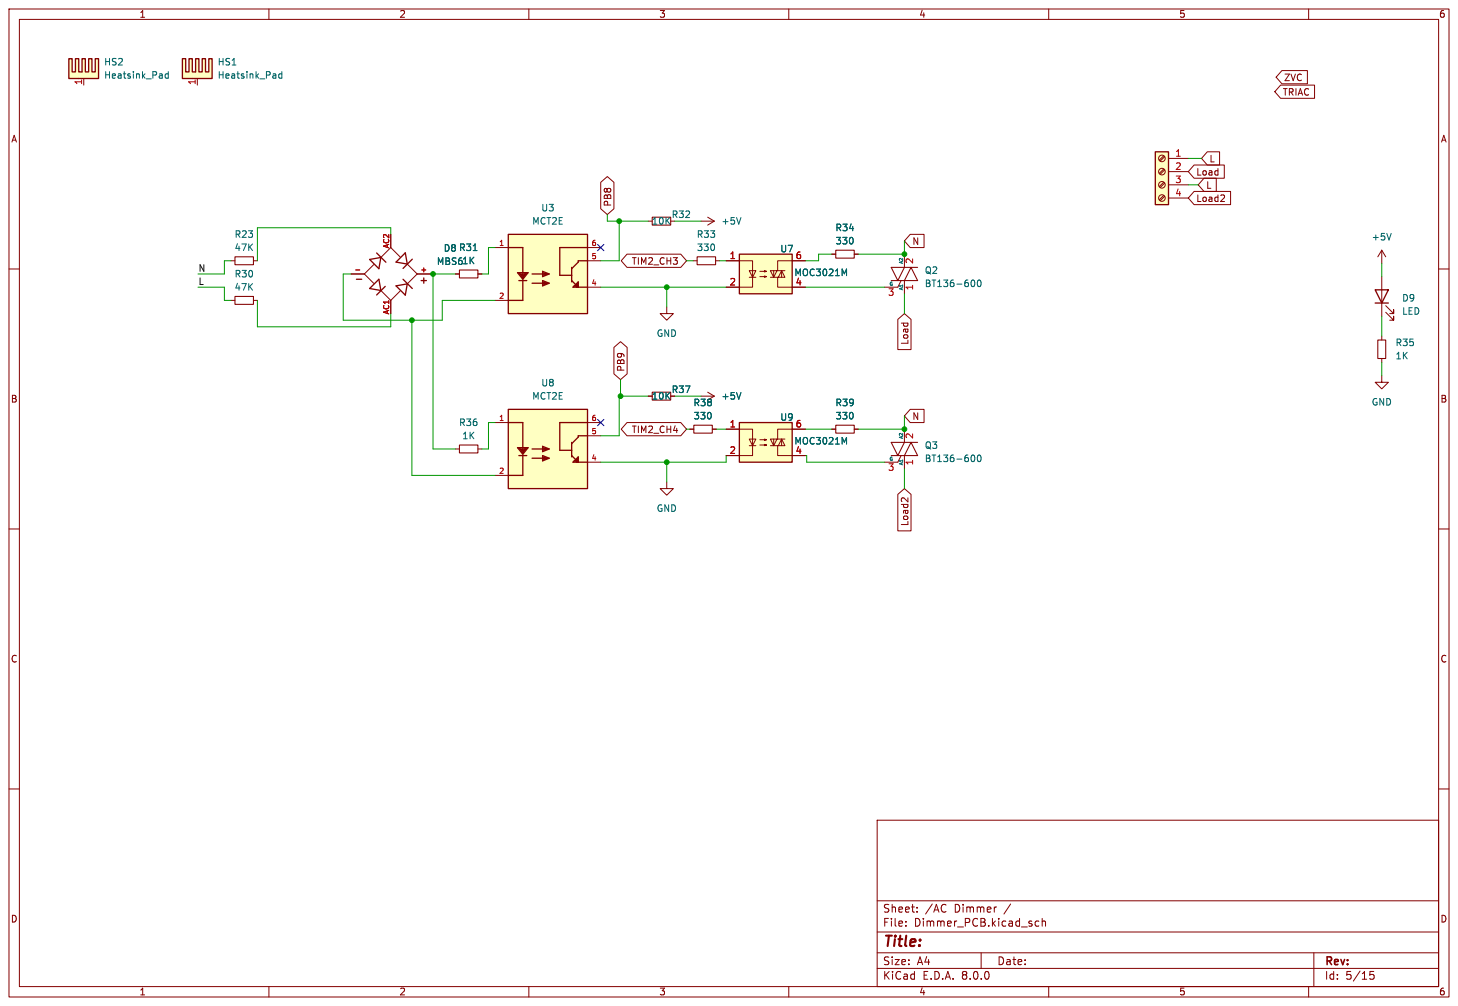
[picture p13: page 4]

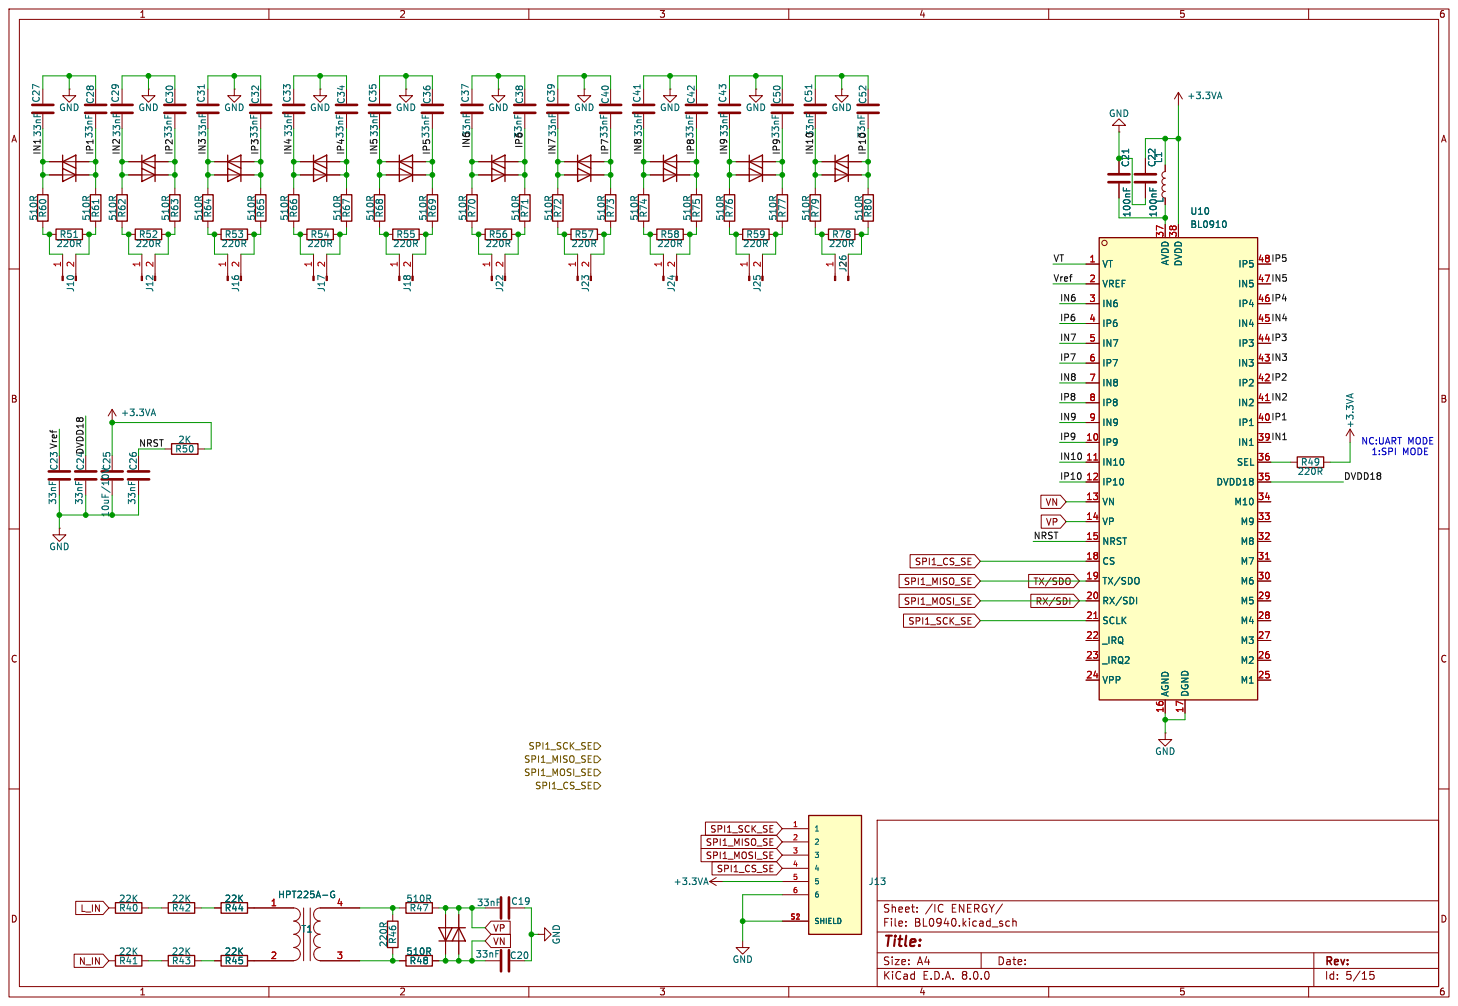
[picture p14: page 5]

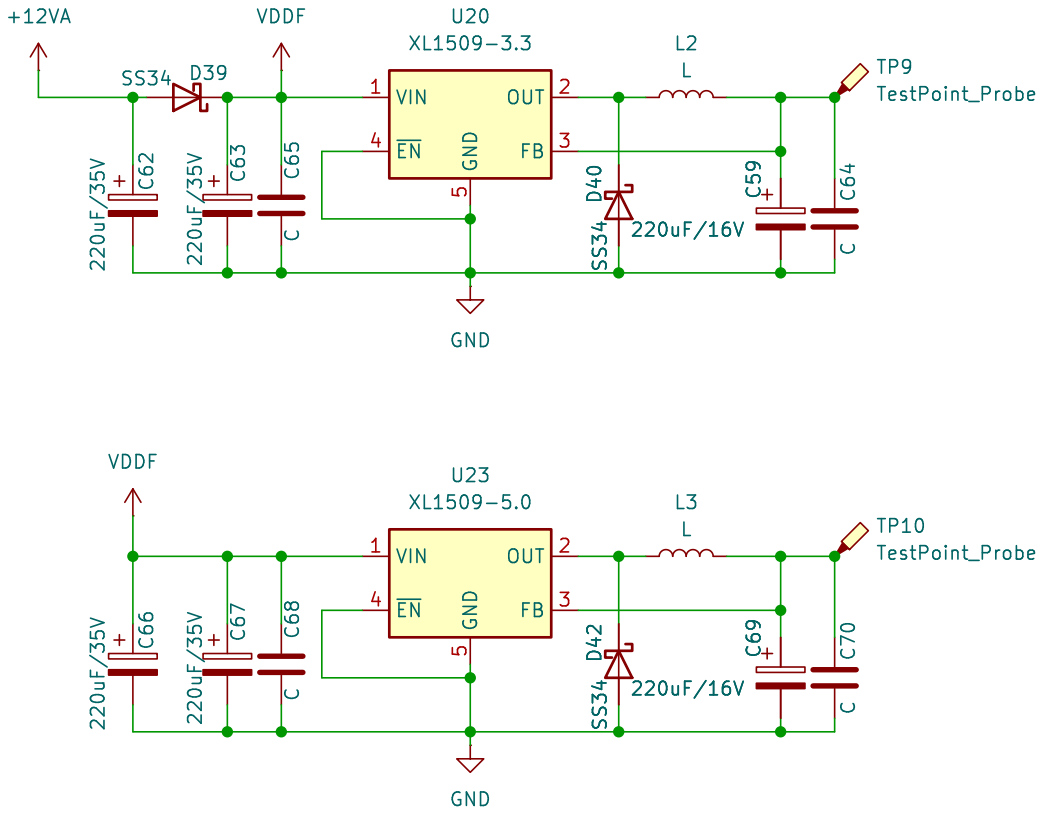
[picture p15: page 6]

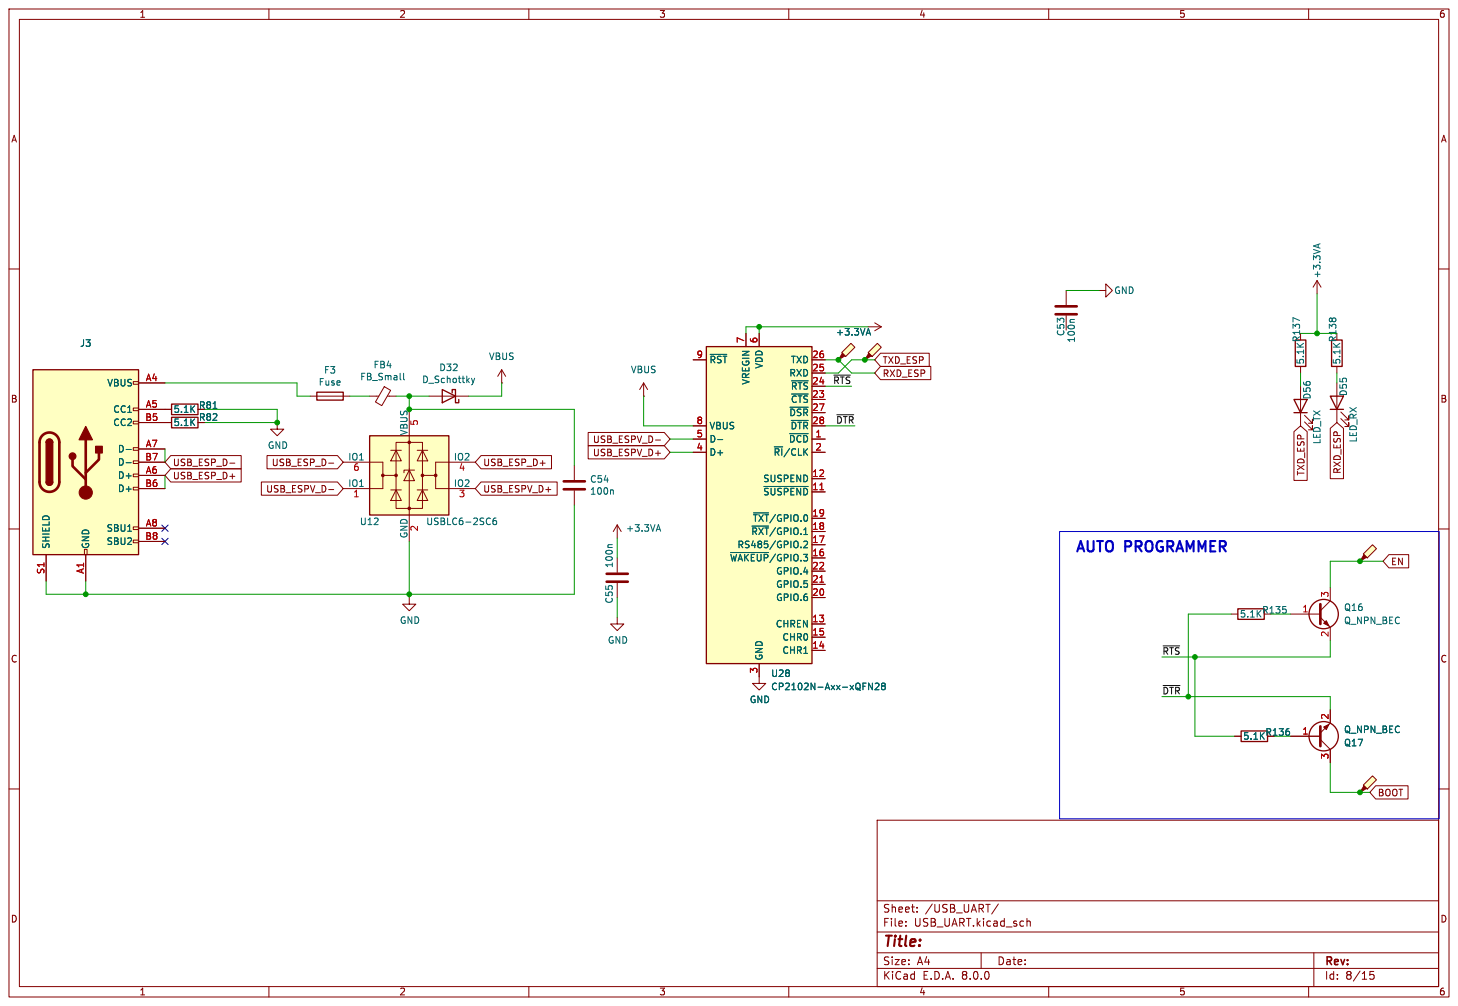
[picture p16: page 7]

7 VBUS 8 ~{RST} 9 U28 CP2102N-Axx-xQFN28 F3 Fuse GND

Id: 8/15 Title: File: USB_UART.kicad_sch Sheet: /USB_UART/

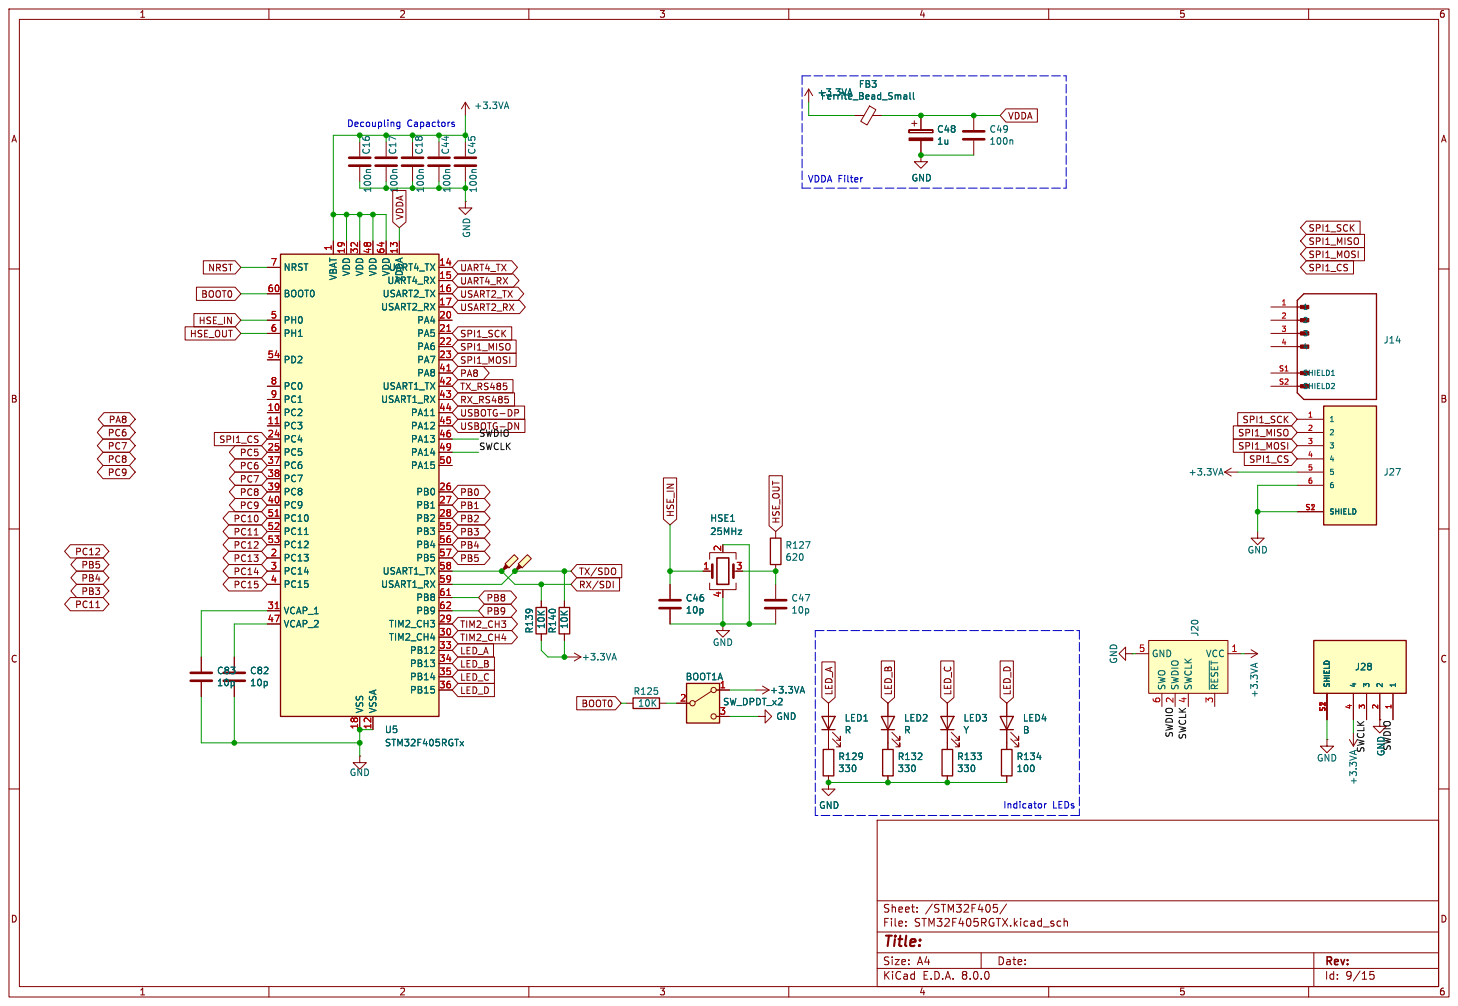
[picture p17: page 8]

Id: 9/15 Title: File: STM32F405RGTX.kicad_sch Sheet: /STM32F405/ GND

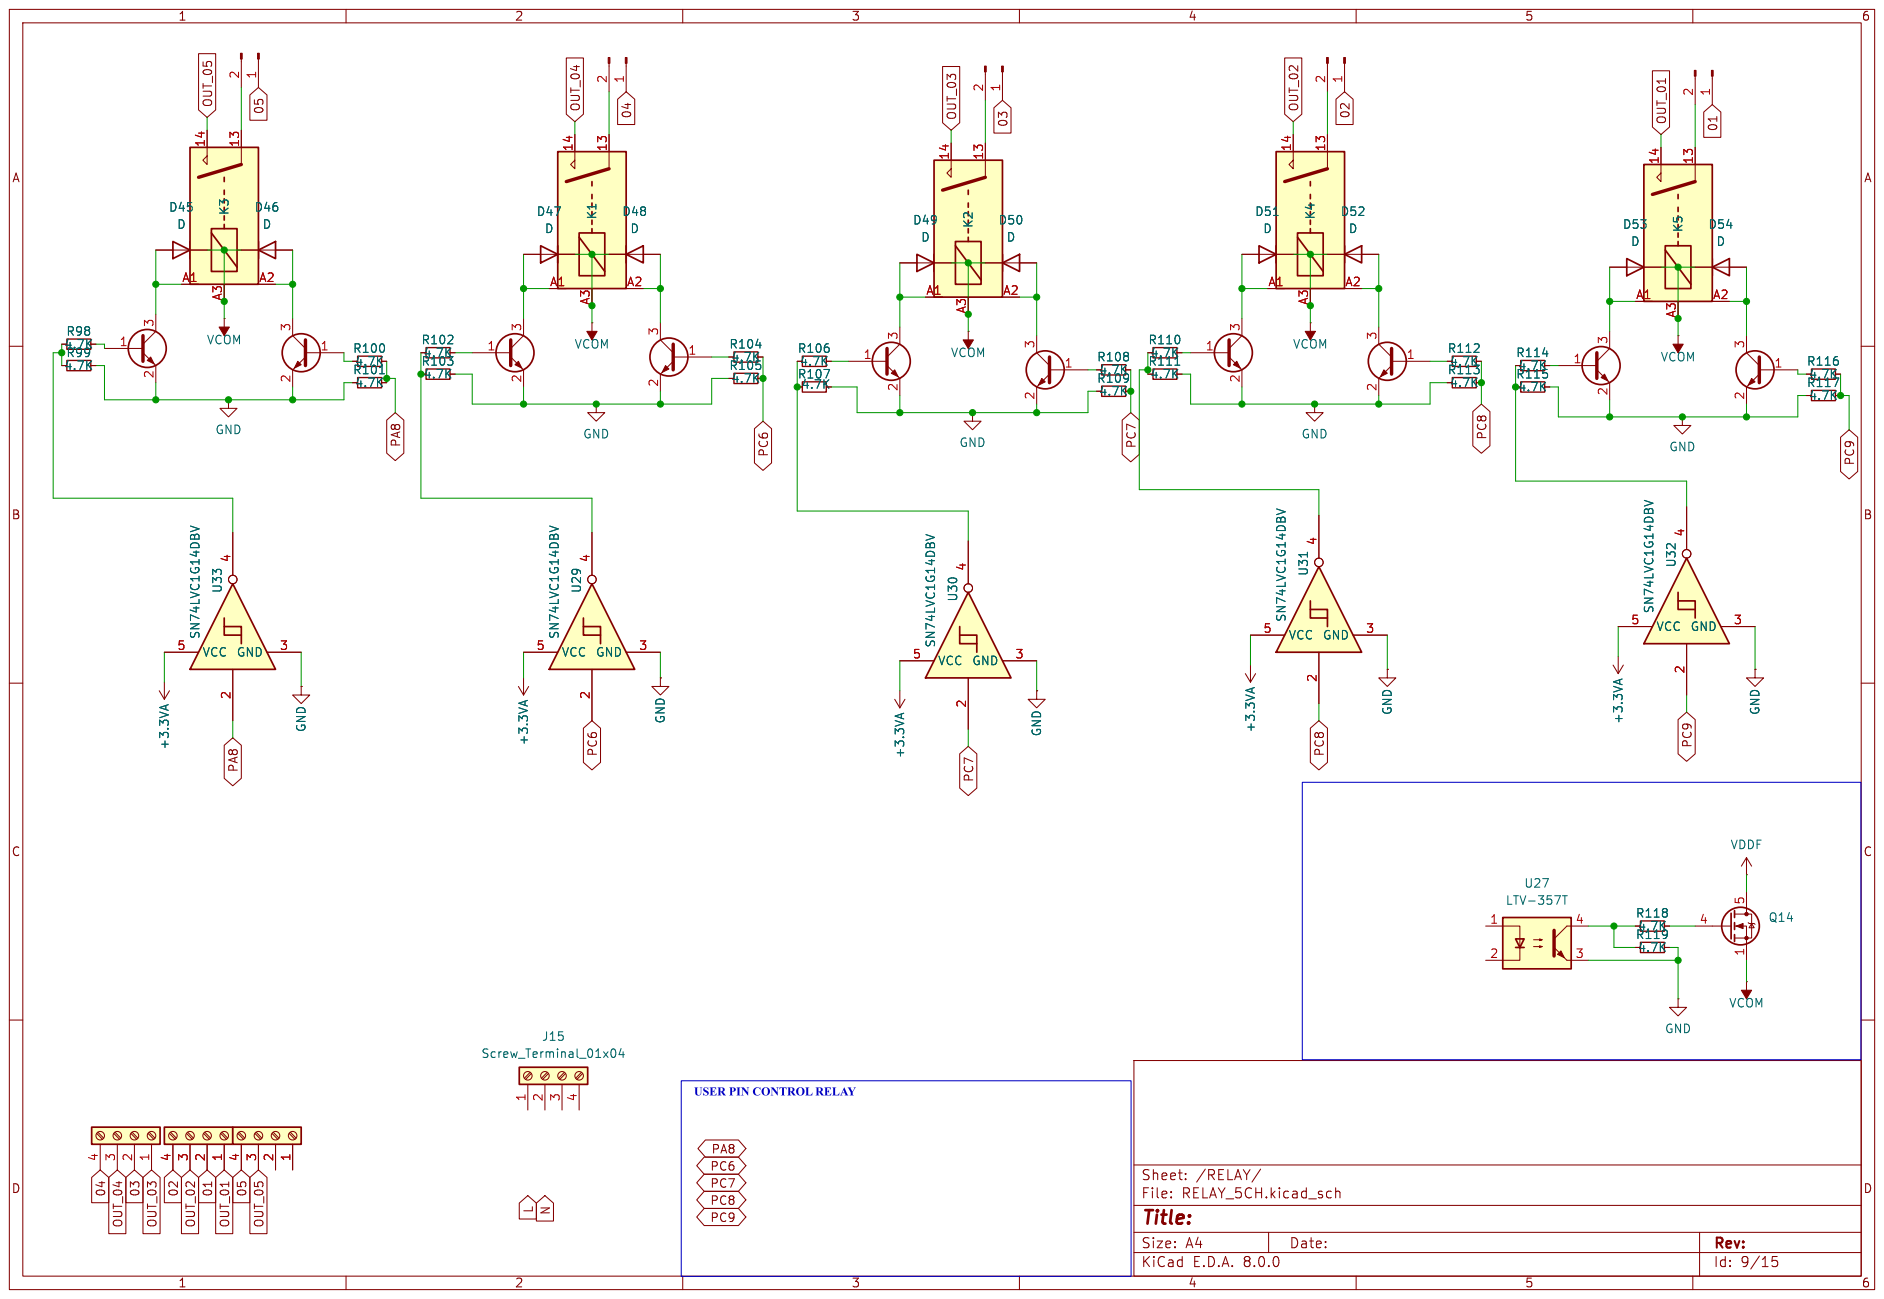
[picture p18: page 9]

USER PIN CONTROL RELAY

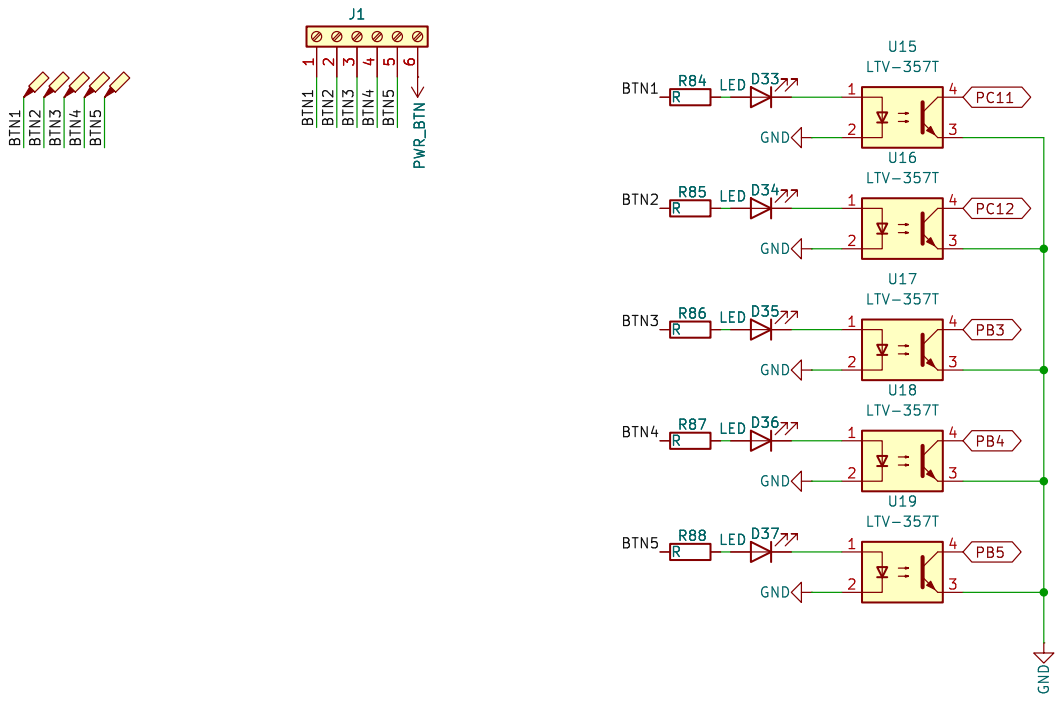
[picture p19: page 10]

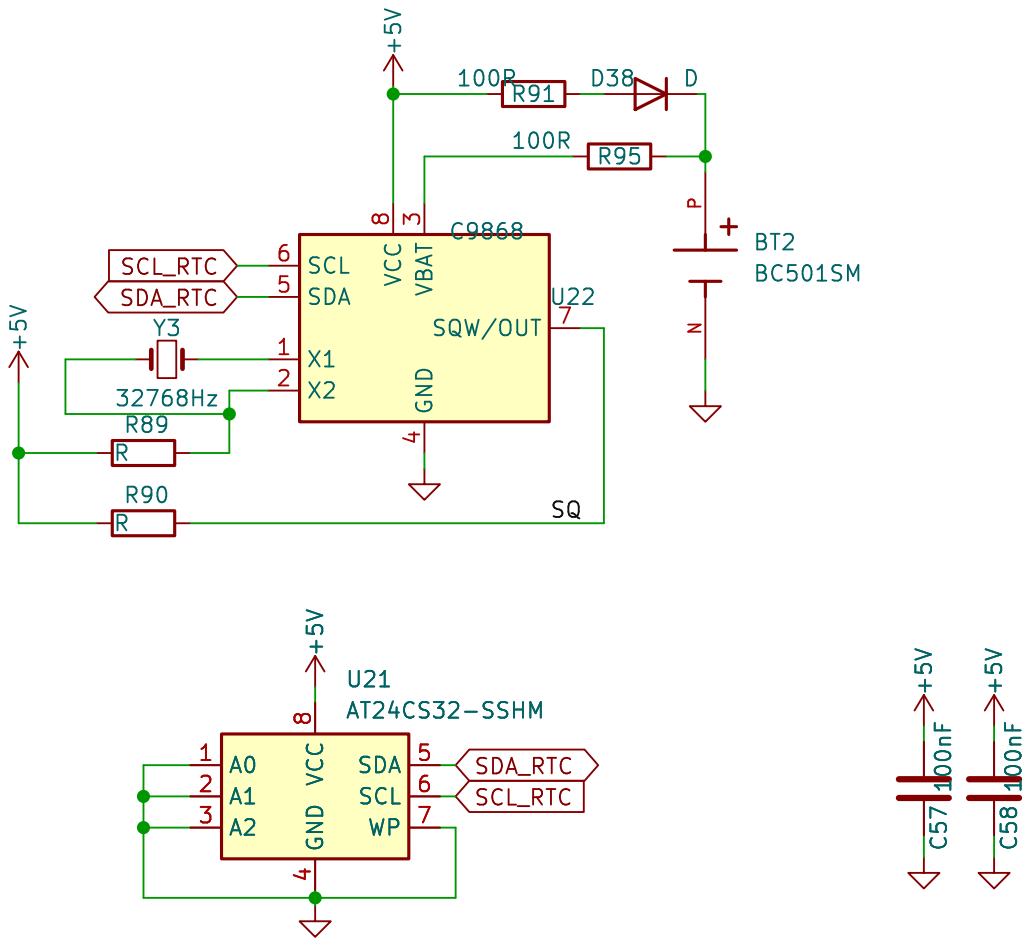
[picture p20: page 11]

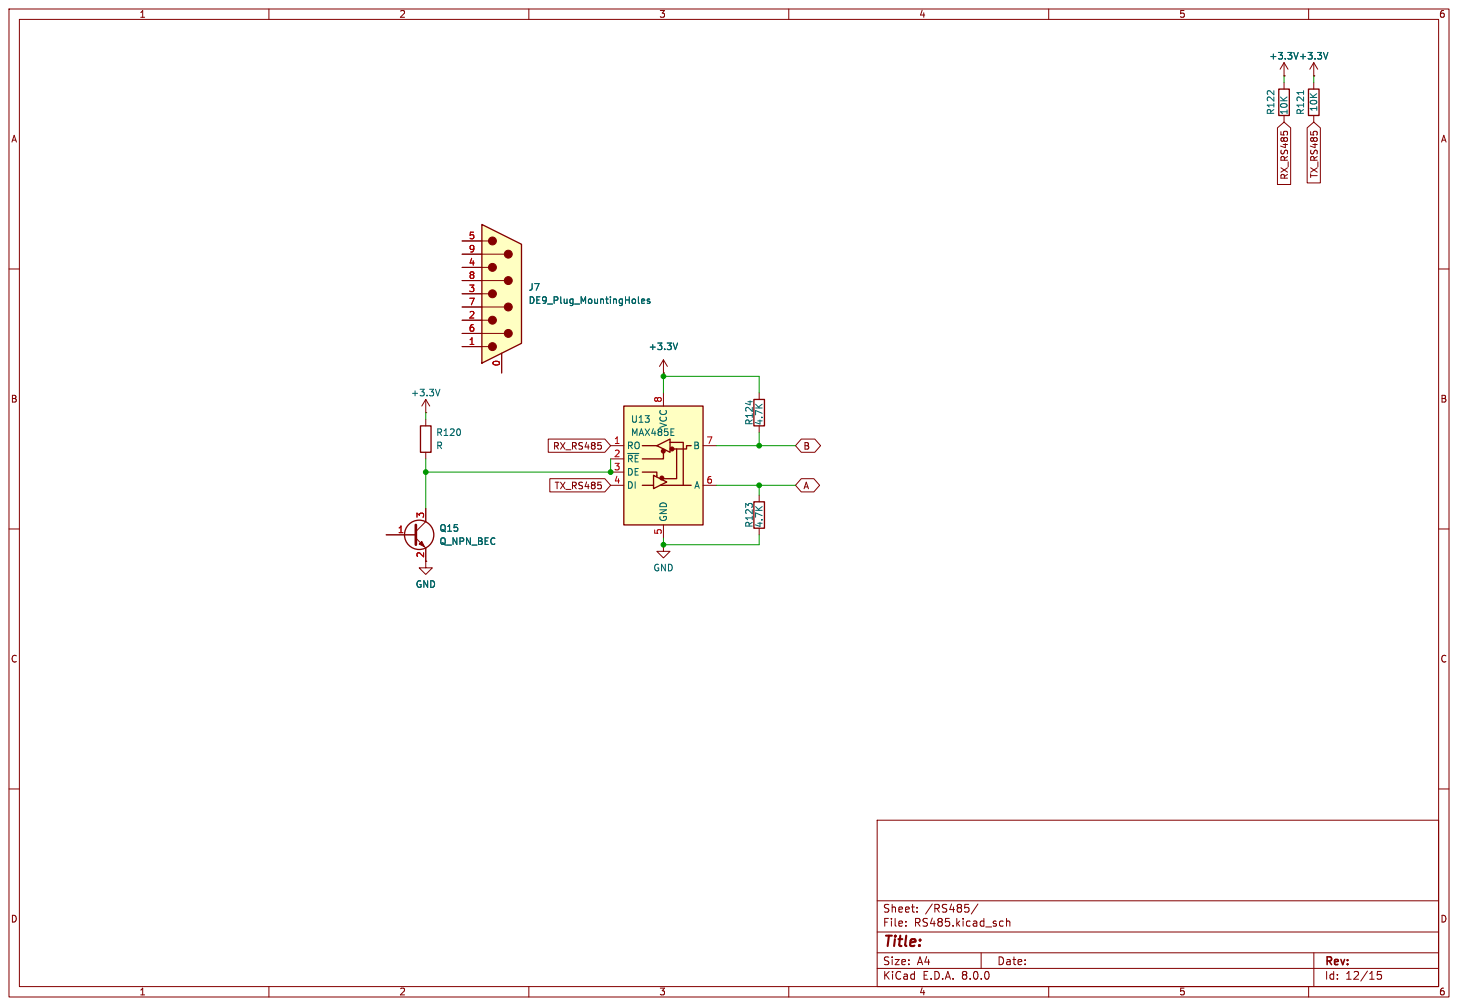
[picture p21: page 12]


1 RXER/PHYAD0 10 CRS_DV/MODE2 11 MDIO 12 MDC 13 ~{INT}/REFCLKO 14 ~{RST} 15 TXEN 16 TXD0 17 TXD1 18 VDD1A 19
LAN8720A VDD2A



Id: 15/15 Title: File: uart.kicad_sch Sheet: /UART_STM/

















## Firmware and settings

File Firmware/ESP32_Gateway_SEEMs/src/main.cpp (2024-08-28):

/*------------------
  Author          : Brorn Munyratanak x Noch Kakada
  Place           : Sen Sok, Phnom Penh
  * Department      : Electronic PPI (B.EcE17-5A14)
  * @Noch Kakada x @Brorn Munyratanak
  * ESP32 Gateway (PlatformIO)

*/
/* Private includes ----------------------------------------------------------*/
#include <Arduino.h>
#include <WiFi.h>
#include <ArduinoOTA.h>
#include <Arduino_ESP32_Updater.h>
#include <Arduino_MQTT_Client.h>
#include <ThingsBoard.h>
/*------------------*/
//#include <Ethernet.h> //Function to call RJ45 ethernet port 

/* USER Header END Includes */
/*------------------*/
/*Private define----------------------------------------------------------------*/
#define RXp2 33 // UART pin config GPIO33
#define TXp2 32 // UART pin config GPIO32

typedef struct
{
  float I1;
  float I2;
  float I3;
  float I4;
  float I5;

  float ActivePower1;
  float ActivePower2;
  float ActivePower3;
  float ActivePower4;
  float ActivePower5;

  float energy_value1;
  float energy_value2;
  float energy_value3;
  float energy_value4;
  float energy_value5;

  float Voltage;
  float Freq;
} EnergyPackage;

EnergyPackage received_package;

// Wi-Fi and ThingsBoard configuration
constexpr char WIFI_SSID[] = "BMR";
constexpr char WIFI_PASSWORD[] = "@1234567";
constexpr char TOKEN[] = "rKfyDEr14iQ4oT7ru14y";
constexpr char THINGSBOARD_SERVER[] = "demo.thingsboard.io";
constexpr uint16_t THINGSBOARD_PORT = 1883U;
constexpr uint32_t MAX_MESSAGE_SIZE = 1024U;
bool rpcSubscribed = false; // Indicates if RPC subscription is done

// Initialize WiFi and MQTT clients
WiFiClient wifiClient;
Arduino_MQTT_Client mqttClient(wifiClient);
ThingsBoard tb(mqttClient, MAX_MESSAGE_SIZE);

// Function declarations
void initWiFi();
bool reconnect();
RPC_Response processSetRELAYStatus(const RPC_Data &data, int RLIndex);
void processTime(const JsonVariantConst &data);
 
// Define the array of RPC callbacks
const std::array<RPC_Callback, 5> callbacks = {
    RPC_Callback{"setRLStatus1", [](const RPC_Data &data)
                 { return processSetRELAYStatus(data, 0); }},
    RPC_Callback{"setRLStatus2", [](const RPC_Data &data)
                 { return processSetRELAYStatus(data, 1); }},
    RPC_Callback{"setRLStatus3", [](const RPC_Data &data)
                 { return processSetRELAYStatus(data, 2); }},
    RPC_Callback{"setRLStatus4", [](const RPC_Data &data)
                 { return processSetRELAYStatus(data, 3); }},
    RPC_Callback{"setRLStatus5", [](const RPC_Data &data)
                 { return processSetRELAYStatus(data, 4); }}};

void sendDataToThingsBoard(float Current1, float Current2, float Current3, float Current4, float Current5, float AP1, float AP2, float AP3,  float AP4,  float AP5, 
float EN1, float EN2, float EN3, float EN4, float EN5, float vols, float freq, float TotalEnergy) {

  String jsonData = "{\"Energy1\":" + String(EN1) + ", \"Energy2\":" + String(EN2) + ", \"Energy3\":" + String(EN3) + 
  ", \"Energy4\":" + String(EN4) + ", \"Energy5\":" + String(EN5) + ", \"voltage\":" + String(vols)+ ", \"freq1\":" + String(freq)+ ", \"TotalEN\":" + String(TotalEnergy)+  
  ", \"CurrentI1\":" + String(Current1)+ ", \"CurrentI2\":" + String(Current2)+ ", \"CurrentI3\":" + String(Current3)+ ", \"CurrentI4\":" + String(Current4)+
  ", \"CurrentI5\":" + String(Current5)+ ", \"ActivePower1\":" + String(AP1)+ ", \"ActivePower2\":" + String(AP2)+ ", \"ActivePower3\":" + String(AP3)+ ", \"ActivePower4\":" + String(AP4)+
  ", \"ActivePower5\":" + String(AP5)+ "}" ;

  tb.sendTelemetryJson(jsonData.c_str());
 
}

void sendStateToSTM32(int RLIndex, bool state) //Relay Control
{
  char message;
  switch (RLIndex)
  {
  case 0:
    message = state ? 'A' : 'B';
    break;
  case 1:
    message = state ? 'C' : 'D';
    break;
  case 2:
    message = state ? 'E' : 'F';
    break;
  case 3:
    message = state ? 'G' : 'H';
    break;
  case 4:
    message = state ? 'I' : 'J';
    break;
  default:
    return; // Invalid RELAY index
  }

  // Send the state over UART to STM32
  Serial1.write(message);
}

void setup()
{
  Serial.begin(115200); 
  Serial1.begin(115200, SERIAL_8N1, RXp2, TXp2);
  //setup_ETH();
  // Small delay to ensure the serial monitor is ready
  delay(500);

  // Initialize Wi-Fi connection
  initWiFi();
}

void loop()
{
  //loop_ETH();
  // Read BL0910 data from STM32 as structured package
  if (Serial1.available() >= sizeof(EnergyPackage))
  {
    Serial1.readBytes((char *)&received_package, sizeof(EnergyPackage));

    Serial.print("Current1: ");
    Serial.println(received_package.I1);
    Serial.print("Current2: ");
    Serial.println(received_package.I2);
    Serial.print("Current3: ");
    Serial.println(received_package.I3);
    Serial.print("Current4: ");
    Serial.println(received_package.I4);
    Serial.print("Current5: ");
    Serial.println(received_package.I5);

    Serial.print("ActivePower1: ");
    Serial.println(received_package.ActivePower1);
    Serial.print("ActivePower2: ");
    Serial.println(received_package.ActivePower2);
    Serial.print("ActivePower3: ");
    Serial.println(received_package.ActivePower3);
    Serial.print("ActivePower4: ");
    Serial.println(received_package.ActivePower4);
    Serial.print("ActivePower5: ");
    Serial.println(received_package.ActivePower5);

    Serial.print("Received energy 1: ");
    Serial.println(received_package.energy_value1);
    Serial.print("Received energy 2: ");
    Serial.println(received_package.energy_value2);
    Serial.print("Received energy 3: ");
    Serial.println(received_package.energy_value3);
    Serial.print("Received energy 4: ");
    Serial.println(received_package.energy_value4);
    Serial.print("Received energy 5: ");
    Serial.println(received_package.energy_value5);

    Serial.print("Received Voltage: ");
    Serial.println(received_package.Voltage);
    Serial.print("Received Freq: ");
    Serial.println(received_package.Freq);
  }
  // Small delay to avoid overwhelming the loop
  delay(1000);

  // Attempt to reconnect if the Wi-Fi connection is lost
  if (!reconnect())
  {
    return;
  }

  // Check if we are connected to ThingsBoard
  if (!tb.connected())
  {
    // Attempt to connect to ThingsBoard
    Serial.print("Connecting to: ");
    Serial.print(THINGSBOARD_SERVER);
    Serial.print(" with token ");
    Serial.println(TOKEN);
    if (!tb.connect(THINGSBOARD_SERVER, TOKEN, THINGSBOARD_PORT))
    {
      Serial.println("Failed to connect");
      return;
    }
  }
  // Subscribe to RPC callbacks if not already subscribed
  if (!rpcSubscribed)
  {
    Serial.println("Subscribing for RPC...");
    if (tb.RPC_Subscribe(callbacks.cbegin(), callbacks.cend()))
    {
      rpcSubscribed = true;
      Serial.println("RPC subscription successful");
    }
    else
    {
      Serial.println("Failed to subscribe for RPC");
    }
  }

  // Generate and send random values every 10 seconds
  static unsigned long lastTempRead = 0;
  if (millis() - lastTempRead > 10000)
  {
    lastTempRead = millis();
    float Current1= received_package.I1;
    float Current2= received_package.I2;
    float Current3= received_package.I3;
    float Current4= received_package.I4;
    float Current5= received_package.I5;

    float AP1= received_package.ActivePower1;
    float AP2= received_package.ActivePower2;
    float AP3= received_package.ActivePower3;
    float AP4= received_package.ActivePower4;
    float AP5= received_package.ActivePower5;
    
    float EN1 = received_package.energy_value1;
    float EN2 = received_package.energy_value2;
    float EN3 = received_package.energy_value3;
    float EN4 = received_package.energy_value4;
    float EN5 = received_package.energy_value5;

    float vols = received_package.Voltage;
    float freq = received_package.Freq;
    float TotalEnergy = EN1 + EN2 + EN3 +EN4 + EN5;  
   sendDataToThingsBoard(Current1, Current2, Current3, Current4, Current5, AP1, AP2, AP3, AP4, AP5, EN1, EN2, EN3, EN4, EN5, vols, freq, TotalEnergy);
  }

  // Maintain the connection and process incoming messages
  tb.loop();
}
void initWiFi()
{
  // Start the connection to the Wi-Fi network
  Serial.println("Connecting to AP ...");
  WiFi.begin(WIFI_SSID, WIFI_PASSWORD);
  while (WiFi.status() != WL_CONNECTED)
  {
    delay(500);
    Serial.print(".");
  }
  Serial.println("Connected to AP");
}

bool reconnect()
{
  // Check the Wi-Fi connection status and reconnect if necessary
  if (WiFi.status() != WL_CONNECTED)
  {
    initWiFi();
  }
  return WiFi.status() == WL_CONNECTED;
}

RPC_Response processSetRELAYStatus(const RPC_Data &data, int RLIndex)
{
  // Process the RPC request to change the LED state
  int dataInt = data;
  if (RLIndex >= 0 && RLIndex < 5)
  {
    bool States = dataInt == 1; // Update the LED state based on the received data
    Serial.print("BreakCircuit ");
    Serial.print(RLIndex + 1);
    Serial.println(States ? " ON" : " OFF");
    // Send the state to STM32 via UART
    sendStateToSTM32(RLIndex, States);
    return RPC_Response("newStatus", dataInt); // Respond with the new status
  }
  return RPC_Response("error", "Invalid LED index");
}

void processTime(const JsonVariantConst &data)
{
  // Process the RPC response containing the current time
  Serial.print("Received time from ThingsBoard: ");
  Serial.println(data["time"].as<String>());
}

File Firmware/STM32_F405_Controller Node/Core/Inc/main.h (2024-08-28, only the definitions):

#define CON_CoilRL_Pin GPIO_PIN_13
#define CON_CoilRL_GPIO_Port GPIOC
#define CS_Pin GPIO_PIN_4
#define CS_GPIO_Port GPIOA
#define TRI2_Pin GPIO_PIN_10
#define TRI2_GPIO_Port GPIOB
#define TRI1_Pin GPIO_PIN_11
#define TRI1_GPIO_Port GPIOB
#define LED_A_Pin GPIO_PIN_12
#define LED_A_GPIO_Port GPIOB
#define LED_B_Pin GPIO_PIN_13
#define LED_B_GPIO_Port GPIOB
#define LED_C_Pin GPIO_PIN_14
#define LED_C_GPIO_Port GPIOB
#define LED_D_Pin GPIO_PIN_15
#define LED_D_GPIO_Port GPIOB
#define RL4_Pin GPIO_PIN_6
#define RL4_GPIO_Port GPIOC
#define RL3_Pin GPIO_PIN_7
#define RL3_GPIO_Port GPIOC
#define RL2_Pin GPIO_PIN_8
#define RL2_GPIO_Port GPIOC
#define RL1_Pin GPIO_PIN_9
#define RL1_GPIO_Port GPIOC
#define RL5_Pin GPIO_PIN_8
#define RL5_GPIO_Port GPIOA
#define Zero_Cross2_Pin GPIO_PIN_8
#define Zero_Cross2_GPIO_Port GPIOB
#define Zero_Cross1_Pin GPIO_PIN_9
#define Zero_Cross1_GPIO_Port GPIOB

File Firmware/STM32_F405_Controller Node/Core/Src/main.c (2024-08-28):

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
/* Includes ------------------------------------------------------------------*/
#include "main.h"
#include "tim.h"
#include "usart.h"
#include "usb_otg.h"
#include "gpio.h"

/* USER CODE BEGIN Includes */
#include "math.h"
#include "stdio.h"
#include "stdlib.h"
#include "stdint.h"
#include "stdbool.h"

/* USER CODE END Includes */

/* USER CODE BEGIN PTD */
typedef union
{
		uint8_t 	B8[4];
		uint32_t	B32;
}B32_B8_TypeDef;

typedef enum
{
	COM_OK			=0x00U,
	COM_ERROR		=0x01U,
	COM_CHKERR	=0x02U
}Com_StatusTypeDef;

typedef enum
{
	OTP_SUCCESS	=0x01U,
	OTP_Fail=0x00U
}OTP_ProgStatusTpyeDef;

typedef struct
{
	uint16_t RMS_1;			//XX.XXX	A		0.001A/LSB
	uint16_t RMS_2;
	uint16_t RMS_3;
	uint16_t RMS_4;
	uint16_t RMS_5;
	uint16_t RMS_6;
	uint16_t RMS_7;
	uint16_t RMS_8;
	uint16_t RMS_9;
	uint16_t RMS_10;
	uint16_t RMS_V;			//XXX.X	 V			0.1Volts/LSB
	uint16_t WATT_1;		//XXXX.X W		    0.1Watt/LSB
	uint16_t WATT_2;
	uint16_t WATT_3;
	uint16_t WATT_4;
	uint16_t WATT_5;
	uint16_t WATT_6;
	uint16_t WATT_7;
	uint16_t WATT_8;
	uint16_t WATT_9;
	uint16_t WATT_10;
	uint16_t Energy_1;		//XXXXXX	kWh   Degree of electricity/LSB, maximum 65,535 degrees of electricity
	uint16_t Energy_2;
	uint16_t Energy_3;
	uint16_t Energy_4;
	uint16_t Energy_5;
	uint16_t Energy_6;
	uint16_t Energy_7;
	uint16_t Energy_8;
	uint16_t Energy_9;
	uint16_t Energy_10;
	uint16_t Energy_Sum;
	uint16_t Period;		//XX.XX	Hz		0.01Hz/LSB
	uint16_t TPS1;			//XX.XX   			0.01 °C/LSB
	uint16_t TPS2;
}Elect_StructDef;

typedef struct
{
	uint16_t	Cnt1;
	uint16_t	Cnt2;
	uint16_t	Cnt3;
	uint16_t	Cnt4;
	uint16_t	Cnt5;
	uint16_t	Cnt6;
	uint16_t	Cnt7;
	uint16_t	Cnt8;
	uint16_t	Cnt9;
	uint16_t	Cnt10;
	uint16_t  Cnt_Sum;
}Eng_CFCnt_StructDef;

//Data for electrical energy calculation
typedef struct
{
	uint16_t Energy001;		 //Electricity accumulation of more than 1 degree
	uint16_t cnt_remainder;	 //pulse base of 1 degree of electricity
}Eng_Cal_StructDef;


typedef struct {
	float Current1;
	float Current2;
	float Current3;
	float Current4;
	float Current5;

	float AP1; //Active Power
	float AP2;
	float AP3;
	float AP4;
	float AP5;

    float energy_value1;
    float energy_value2;
    float energy_value3;
    float energy_value4;
    float energy_value5;

    float Voltage;
    float Freq;
} BL0910Data;

//typedef struct{
//	bool swa;
//	bool swb;
//	bool swc;
//	bool swd;
//	bool swe;
//
//}SwitchTypedef;  //5 digital input value (Manual Button)

/* USER CODE END PTD */

/* USER CODE BEGIN PD */

#define Current_K	    19154
#define Voltage_k	    9000
#define Power_K		    54805
#define Energy_K	    8972
#define Energy_Sum_K 	560

//#define Power_K		    3425
//#define Current_K	    11971 193653.14
#define Sys_Rst								0
#define CalReg_RST							1

#define Addr_VERSION						0x00
#define	Addr_1_WAVE							0x01
#define	Addr_2_WAVE							0x02
#define	Addr_3_WAVE							0x03
#define	Addr_4_WAVE							0x04
#define	Addr_5_WAVE							0x05
#define	Addr_6_WAVE							0x06
#define	Addr_7_WAVE							0x07
#define	Addr_8_WAVE							0x08
#define	Addr_9_WAVE							0x09
#define	Addr_10_WAVE						0x0A
#define	Addr_V_WAVE							0x0B

#define Addr_1_RMS							0x0C
#define Addr_2_RMS							0x0D
#define Addr_3_RMS							0x0E
#define Addr_4_RMS							0x0F
#define Addr_5_RMS							0x10
#define Addr_6_RMS							0x11
#define Addr_7_RMS							0x12
#define Addr_8_RMS							0x13
#define Addr_9_RMS							0x14
#define Addr_10_RMS							0x15

#define Addr_V_RMS							0x16
#define Addr_1_FAST_RMS						0x17
#define Addr_2_FAST_RMS						0x18
#define Addr_3_FAST_RMS						0x19
#define Addr_4_FAST_RMS						0x1A
#define Addr_5_FAST_RMS						0x1B
#define Addr_6_FAST_RMS						0x1C
#define Addr_7_FAST_RMS						0x1D
#define Addr_8_FAST_RMS						0x1E
#define Addr_9_FAST_RMS						0x1F
#define Addr_10_FAST_RMS					0x20
#define Addr_V_FAST_RMS						0x21

#define Addr_WATT1							0x22 //Active power
#define Addr_WATT2							0x23
#define Addr_WATT3							0x24
#define Addr_WATT4							0x25
#define Addr_WATT5							0x26
#define Addr_WATT6							0x27
#define Addr_WATT7							0x28
#define Addr_WATT8							0x29
#define Addr_WATT9							0x2A
#define Addr_WATT10							0x2B
#define Addr_WATT							0x2C //REG watt total

#define Addr_VAR							0x2D
#define Addr_VA								0x2E
#define Addr_CF1_CNT						0x2F
#define Addr_CF2_CNT						0x30
#define Addr_CF3_CNT						0x31
#define Addr_CF4_CNT						0x32
#define Addr_CF5_CNT						0x33
#define Addr_CF6_CNT						0x34
#define Addr_CF7_CNT						0x35
#define Addr_CF8_CNT						0x36
#define Addr_CF9_CNT						0x37
#define Addr_CF10_CNT						0x38
#define Addr_CF_CNT							0x39
#define Addr_CFQ_CNT						0x3A
#define Addr_CFS_CNT						0x3B
#define Addr_ANGLE1							0x3C
#define Addr_ANGLE2							0x3D
#define Addr_ANGLE3							0x3E
#define Addr_ANGLE4							0x3F
#define Addr_ANGLE5							0x40
#define Addr_ANGLE6							0x41
#define Addr_ANGLE7							0x42
#define Addr_ANGLE8							0x43
#define Addr_ANGLE9							0x44
#define Addr_ANGLE10						0x45
#define Addr_1_FAST_RMS_HOLD		0x46
#define Addr_2_FAST_RMS_HOLD		0x47
#define Addr_3_FAST_RMS_HOLD		0x48
#define Addr_4_FAST_RMS_HOLD		0x49
#define Addr_PF								0x4A
#define Addr_LINE_WATTHR					0x4B
#define Addr_LINE_VARHR						0x4C
#define Addr_SIGN							0x4D
#define Addr_PERIOD							0x4E

#define Addr_STATUS1						0x54
#define Addr_STATUS2						0x55
#define Addr_STATUS3						0x56
#define Addr_5_FAST_RMS_HOLD		0x57
#define Addr_6_FAST_RMS_HOLD		0x58
#define Addr_7_FAST_RMS_HOLD		0x59
#define Addr_8_FAST_RMS_HOLD		0x5A
#define Addr_9_FAST_RMS_HOLD		0x5B
#define Addr_10_FAST_RMS_HOLD		0x5C
#define Addr_VAR1							0x5D
#define Addr_TPS1							0x5E
#define Addr_TPS2							0x5F

#define Addr_GAIN1							0x60
#define Addr_GAIN2							0x61
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

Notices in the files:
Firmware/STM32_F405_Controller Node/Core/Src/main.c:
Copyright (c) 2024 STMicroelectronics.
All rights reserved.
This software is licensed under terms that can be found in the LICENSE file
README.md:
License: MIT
